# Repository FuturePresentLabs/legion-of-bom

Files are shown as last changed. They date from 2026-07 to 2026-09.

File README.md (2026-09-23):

<div align="center">

# legion-of-bom

### Prompt to PCB.

*One sentence in. A placed, routed, DRC-checked board out — and every value on it has a receipt.*









*SKiDLs are better with friends.*

</div>

```bash
lob spec stm32-codec --brief "stereo line in and out, no I2C setup" --out design
lob schematic design.json --out board.py
lob board board.py && lob drc out/board/board.kicad_pcb
```

That's a design brief becoming an STM32H743 audio board: a codec **decided**
from what you asked for, pins wired by the names in the official KiCad symbols,
every capacitor and strap **cited** to a page of a pinned datasheet, then placed,
routed and checked by KiCad's own DRC. No schematic drawn by hand, no pinout
typed from memory, no value you can't trace.

**legion-of-bom** turns circuit-as-code into manufacturing-ready outputs —
placed and routed boards, panels, Gerbers, a JLCPCB assembly package, build
guides and a priced BOM — in one pipeline instead of KiCad + spreadsheets +
manual ordering scattered across tools. It started with
[Puget Audio](https://pugetaudio.com) Eurorack modules and now designs
microcontroller boards too.

- 🎛️ **Ships real hardware.** The Puget Audio slew limiter builds from source to a
  DRC-clean, 0-unconnected fab package.
- 🧠 **Decides, doesn't hallucinate.** Every design choice is a bounded, typed
  decision — a choice, a probability, a rubric score — never free text. The
  rest is a pure function of those answers.
- 🧾 **Cites everything.** 0.5 mm pins escape through a router that measures
  clearance in exact geometry; decoupling values come with a verbatim datasheet
  quote a machine checks; anything it can't check waits for a human to sign.
- 📏 **Keeps score.** [PCBBench](https://github.com/FuturePresentLabs/pcbbench)
  runs brief → board → DRC against a rubric, so "does it work" has a number.

*(Badge numbers are generated — run `scripts/update-badges.sh` after tests,
families or datasheets change; don't hand-edit them.)* See
[`DESIGN.md`](./DESIGN.md) for the full design and [marbles](#issue-tracking)
for the live task graph.

## The pipeline

A circuit is defined as code (SKiDL), or decided from a design brief and then
rendered to code, and flows through composable stages:

```
brief ─(lob spec)─► spec ─(lob schematic)─► SKiDL circuit
                                              │
        lob run:  netlist → parse → ERC → simulate (ngspice) → verify → BOM
        lob board: place → legalize → route → .kicad_pcb → lob drc (kicad-cli)
        lob fab / guide / build: Gerbers + drill + CPL + BOM, assembly guide, Visual BOM
```

- **Typed decisions, curated families.** `lob spec <family> --brief "…"` asks a
  small number of bounded questions (a choice, a probability, a rubric score —
  never free text) of a System One–compatible endpoint through the shared
  [`ooda`](https://github.com/FuturePresentLabs/ooda) client, and writes a spec. `lob schematic` renders
  the circuit as a pure function of that spec. Families today: `fuzz-pedal`
  (plus `lob spec-chain` for chained gain stages) and `stm32-codec` (an
  STM32H743 with a PCM5102A + PCM1808, WM8731 or ES8388 codec).
- **Cited, not remembered.** A family's pinouts come from the official KiCad
  symbols, connected by pin name and checked against the symbol file (including
  pin-mux alternates). Every component value carries a verbatim quote from a
  page of a pinned datasheet — distributor copy, URL + SHA-256 — that is checked
  mechanically with `pdftotext`. Values read off a figure, or not stated in any
  pinned source, are recorded as readings; `lob schematic` lists every one no
  person has confirmed yet.
- **Layout for Eurorack and free boards.** A board with a panel is laid out
  against it (the PCB also derives its own minimum-width panel); a board without
  one gets a free rectangle sized to its parts. A negotiated-congestion router
  escapes 0.5 mm-pitch QFP/QFN pins and measures clearance in exact geometry.
- **Measured, not assumed.** Simulation checks textbook circuits against
  analytic values, `lob scope-probe` measures clipping as a SPICE claim, and
  [PCBBench](https://github.com/FuturePresentLabs/pcbbench) scores whole runs — brief to DRC — against a
  task rubric.

## Architecture

- **`legion-of-bom-core`** (`crates/core`) — the pipeline library: circuit model
  and the `CircuitSource` trait every stage reads through (DSL-agnostic, DESIGN.md
  2.3/3.3), placement, routing, rules, panels, fab, guides, SPICE, the curated
  families (`family.rs`) and datasheet citations (`datasheet.rs`).
- **`lob`** (`crates/cli`) — the command-line interface, a thin wrapper over the
  core library.
- **`legion-of-bom-web`** (`crates/web`) — the local read-only dashboard
  (`lob serve`) over the same core.
- **Parts library** — a global SQLite store (via SQLx) of part definitions keyed
  by MPN, with a `verified_by_human` gate on real board/BOM generation
  (`lob parts …`). Distributor clients (Mouser, JLCPCB) are sandboxed Lua scripts,
  not built-in Rust.

## Setup

Rust toolchain, plus the external tools the stages shell out to — each stage
fails with a clear error, never a panic, when its tool is missing:

- **KiCad 9** (`kicad-cli`, symbol + footprint libraries) — boards, DRC, fab
- **Python + SKiDL** in a `.venv` (or `$VIRTUAL_ENV`) — circuit scripts
- **ngspice** — simulation
- **poppler** (`pdftotext`) — datasheet citation checks

`lob doctor` reports what it found. API keys (`OODA_API_KEY` for `lob spec`,
`MOUSER_API_KEY`, `JLCPCB_*`) go in `~/.lob/credentials` or a repo `.env` — see
[`.env.example`](./.env.example).

## Quickstart

```bash
cargo run -p legion-of-bom-cli -- run examples/rc_lowpass.py        # simulate a textbook filter

lob spec stm32-codec --brief "stereo line in/out, no I2C setup" --out design
lob schematic design.json --out board.py                            # + unconfirmed readings
lob run board.py && lob board board.py && lob drc out/board/board.kicad_pcb
```

## Dev loop

Run the gates in this order — cheapest feedback first:

```bash
cargo check          # fast type/borrow check (run first, run often)
cargo test           # unit tests
cargo build          # produce the lob binary

cargo fmt --check    # formatting
cargo clippy --all-targets --all-features -- -D warnings   # lints, warnings are errors

# Checks that need the installed KiCad libraries and the pinned datasheets:
cargo test -p legion-of-bom-core -- --ignored
```

## Vendored assets

`assets/` carries real, sourced third-party panel-component footprints and
3D meshes (Eurorack-style jacks, pots, LEDs, switches) for hardware KiCad's
own stock libraries don't cover well. See [`assets/CREDITS.md`](assets/CREDITS.md)
for exact provenance, licenses (Unlicense, CC-BY 4.0 — both redistribution-
clean), and where to re-fetch them.

## Issue tracking

Work is tracked in **[marbles](https://github.com/FuturePresentLabs/marbles)**
(hosted, one writer per project), not markdown TODOs. Ids carried over unchanged
from beads. The roadmap (DESIGN.md §14) is modeled as epics:

```bash
marbles ready                 # what's available to work on now
marbles list --json           # everything, machine-readable
marbles show <id> --json      # details + dependencies
```

Closed means merged: finished work moves to `review` with its PR and closes on
merge.

## License

[AGPL-3.0-or-later](./LICENSE).

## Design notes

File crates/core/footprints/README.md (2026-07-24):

# Bundled sub-board footprints

Real KiCad footprints for Daisy sub-boards, embedded so a circuit can reference
them via the `LobModule:` library (see `crates/core/src/subboard.rs`).

`Daisy-Boards.pretty/` is vendored from Electrosmith's **DaisyKiCad** library
(https://github.com/electro-smith/DaisyKiCad), MIT-licensed — see
`DaisyKiCad-LICENSE`. Pad names are the physical Daisy pin names (`A1`…`D10` /
`A1`…`E10`), so nets map straight to the datasheet pinout.

| Footprint | Module | Mount |
|---|---|---|
| `DAISY_PATCH_SM` | Patch Submodule | through-hole 2×5 headers ×4 |
| `DAISY_PATCH_SM_SMT`  | Patch Submodule | SMT headers |
| `DAISY_SEED2_DFM` | Seed2 DFM | SMT (1.27 mm) female landing |
| `DAISY_SEED2_DFM_PTH` | Seed2 DFM | through-hole (1.27 mm) female landing |

The Daisy Seed itself is synthesized in `subboard.rs` (not vendored here).

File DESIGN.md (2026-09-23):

# Puget Audio Board Pipeline — DESIGN.md

Status: DRAFT — sections 1-3 filled in, 4-15 pending.

## Table of Contents

1. **Vision & Scope**
   1.1 Problem statement
   1.2 What "done" looks like
   1.3 Non-goals (v1)

2. **Architecture Overview**
   2.1 Pipeline stages (map to the 8-step loop)
   2.2 Orchestration model (CLI tool? library? workflow engine?)
   2.3 Canonical circuit representation (the IR that DSLs compile to / tools read from)
   2.4 Repo & project structure
   2.5 Multi-tenancy & auth
   2.6 Storage split: SQL stores vs. git-native

3. **Circuit Definition Layer**
   3.1 SKiDL (v1, Python)
   3.2 Path to a native Rust DSL (v2+)
   3.3 DSL-agnostic circuit IR — what it must capture to support multiple frontends
   3.4 Reusable component/subcircuit library (op-amp stages, OTA stages, RIAA networks, etc.)
   3.5 Global parts library (pinout/rating/SPICE-model verification — see also MCP.md)

4. **Validation Layer**
   4.1 ERC (first pass) — what it catches, what it doesn't
   4.2 Project-specific rule extensions (Eurorack power header conventions, panel mount checks)
   4.3 Parts verification gate (filled — see body)

5. **Simulation Layer**
   5.1 ngspice integration
   5.2 PedalKernel integration — reusing the existing accuracy/harness infrastructure
   5.3 What gets simulated pre-layout vs. what waits

6. **Layout & DFM**
   6.1 Format profiles (Eurorack, Guitar Pedal, Rack Mount, Desktop) — anchored connectors
   6.2 2-layer convention (ground pour default)
   6.3 Mode: Analog vs. Digital — cost-function weighting
   6.4 Critical-net tagging in SKiDL
   6.5 Iterative layout loop (place → route → check → repair)
   6.6 KiCad pcbnew integration (from IR/netlist to board file)
   6.7 DFM checks (JLCDFM + mechanical/3D collision checks)
   6.8 Manual layout escape hatch — where the human loop stays in
   6.9 PanelSpec trait — the format-agnostic seam (filled — see body)
   6.10 Silkscreen generation & validation (filled — see body)

7. **Panel Design**
   7.1 DXF output (filled — see body)
   7.2 SVG output (priority raised — see 7.7)
   7.3 KiCad-native panel workflow
   7.4 Mechanical fit checks against PCB (jack/pot alignment)
   7.5 Manual order tracking — no fab-vendor API available (filled — see body)
   7.6 Visual BOM / component sorting sheet (filled — see body)
   7.7 Drilling jigs + Lightburn SVG (filled — see body)
   7.8 Build-guide rendering (filled — see body)
   7.9 Parametric brand identity — curated, not generated (filled — see body)

8. **Manufacturing Outputs**
   8.1 Gerbers via KiCad (v1 path)
   8.2 Direct-to-gerber (future — if/when it's worth it)
   8.3 Output validation before submission

9. **BOM & PCBA Pipeline**
   9.1 BOM generation from IR
   9.2 CPL (component placement list) generation
   9.3 JLCPCB API integration (quoting, order creation, tracking)
   9.4 BOM accuracy/verification — this has to be airtight (filled — see body)
   9.5 Multi-vendor part sourcing rules (JLCPCB basic vs extended, LCSC fallback)
   9.6 Compatible-substitute suggestions (filled — see body)

10. **Thru-Hole BOM & Ordering**
    10.1 Distributor sourcing (LCSC/Mouser/DigiKey)
    10.2 Kitting for in-house assembly at FPL

11. **Part Stock & Inventory Management**
    11.1 Data model (parts, boards, revisions, quantities on hand)
    11.2 Shared-component tracking across SKUs (2OPFM, PHRSR/SCANNER/EG/TVCA, future Winterbloom line)
    11.3 Source of truth — where inventory state actually lives

12. **Reorder Automation**
    12.1 Trigger logic (thresholds, lead-time awareness)
    12.2 n8n integration
    12.3 Human-in-the-loop vs. fully automatic ordering

13. **QC, Test & Revision Control**
    13.1 Bench test / functional test procedure before ship
    13.2 Board revision scheme (silkscreen rev ↔ git tag ↔ IR version)
    13.3 Traceability (which rev shipped to which retailer/order)

14. **Roadmap & Milestones**
    14.1 Phase 0 — demo circuits (RC low-pass filter, then non-inverting op-amp gain
         stage) as end-to-end proof of concept, local-only. Goal: exercise every
         pipeline stage on textbook circuits with known-good answers before risking
         a real product design on an unproven pipeline
    14.2 Phase 1 — slew limiter (first real Puget Audio board), still local/localhost
    14.3 Phase 2 — MVP hardening covering must-have outputs (KiCad/PedalKernel/SPICE)
    14.4 Phase 3 — panel outputs (DXF/SVG/KiCad)
    14.5 Phase 4 — BOM/PCBA hardening + inventory (Dolt) + reorder automation
    14.6 Phase 5 — SaaS-ification: multi-tenancy, auth, hosted remote-repo connections
    14.7 Phase 6 — direct-to-gerber, additional DSLs (stretch)

15. **Open Questions**
    (running list — filled in as we go)

---

## 1. Vision & Scope

### 1.1 Problem statement
Small electronics hardware businesses (starting with Puget Audio) currently manage
circuit design, simulation, layout, BOM/PCBA ordering, and inventory across
disconnected tools — KiCad GUI, spreadsheets, manual retailer ordering. legion-of-bom
unifies this into one pipeline: circuit-as-code in, manufacturing-ready outputs and
live inventory/reorder state out.

### 1.2 What "done" looks like
Phase 0: an RC low-pass filter and a non-inverting op-amp gain stage, each defined in
SKiDL, flow through the full pipeline — validation, ngspice simulation checked against
textbook predicted values, KiCad layout scaffolding, BOM/CPL — entirely on one local
machine, no network-facing component. That proves the loop before any real Puget
Audio product design goes through it. Full "done" (later phases): a user defines a
circuit in SKiDL (or a future DSL) inside a git repo; legion-of-bom runs the same
pipeline, can quote and place a JLCPCB PCBA order via their API, tracks inventory in
Dolt, and triggers reorders — through a web dashboard, usable by more than one
tenant/business.

### 1.3 Non-goals (v1)
- Full autorouting/autoplacement — manual layout stays human-driven initially
- Replacing KiCad's schematic/layout editors outright — legion-of-bom orchestrates
  around them, doesn't replace them
- Multi-tenancy, hosted auth, remote repo connections, billing — v1 is local-only,
  single-user, no network-facing auth surface at all. SaaS-shaping is an
  architectural intent for later, not a v1 requirement

---

## 2. Architecture Overview

### 2.1 Pipeline stages
Maps to the 8-step loop (Sections 4–13 below), plus panel design and QC/revision
control as first-class stages rather than afterthoughts.

### 2.2 Orchestration model
A Rust core library (`legion-of-bom-core`) exposes each pipeline stage as a composable
function/trait. A CLI (`lob`) wraps the library for local, scriptable use. A web
backend (axum — same stack as Understory) wraps the *same* library for the hosted
dashboard, so nothing is web-only — anything the dashboard can do, the CLI can do
headless.

### 2.3 Canonical circuit representation
Deferred per decision: SKiDL-native for now, IR extracted once a second DSL is real.
Flag for later sections: pipeline stages downstream of circuit definition
(validation, sim, layout) should still be written against a thin internal interface
now, even before extraction, so the eventual IR refactor doesn't ripple through
everything that consumes circuit data.

### 2.4 Repo & project structure
- **FuturePresentLabs/legion-of-bom** — the tool itself (core lib + CLI + web
  backend), AGPLv3
- **Board/circuit repos** — one per project (e.g. `puget-audio-2opfm`,
  `puget-audio-slew-limiter`), each can hold multiple related circuits, plain git.
  In v1, these are local clones on the machine running `lob` — the CLI/backend
  shells out to `git` directly, no remote-hosting integration yet. The
  Forestry.io-for-KiCad model (connecting to *someone else's* remote repo) is a v2+
  concern once SaaS-ification happens
- **Inventory data** — lives in Dolt, not in the circuit git repos (see 2.6)

### 2.5 Multi-tenancy & auth (deferred to a later phase)
v1 is local-first and single-user: the CLI runs git commands directly against
locally-cloned repos, and the web dashboard runs on localhost with no auth layer at
all. Multi-tenancy, hosted repo connections, and auth (WebAuthn passkeys vs GitHub
OAuth vs something else) only get designed once the core pipeline loop — schematic
through inventory — actually works end-to-end for one user. Not designing this now
on purpose; revisit in Section 14 roadmap.

### 2.6 Storage split: SQL stores vs. git-native
Circuit definitions (SKiDL files, KiCad projects) stay in plain git — they're
file-based already and git's native diff/PR tooling works well on them. Structured,
cross-project data (parts, panel orders, and eventually stock levels/reorder
thresholds) lives in a SQL store instead, for the query/aggregation layer plain
files can't do well.

Which SQL store is deliberately not one answer for every table. The **parts
library** (Section 6.8, `crates/core/src/parts.rs`) is a single local SQLite file
via `sqlx` — no per-write history, a write just overwrites what was there; nothing
in its verification-gate workflow needed git-like branching/diffing, so paying
for it was pure overhead. **Panel orders** (Section 7.5, `crates/core/src/panel.rs`)
are still Dolt-backed, unmigrated — that store keeps the git-like versioning this
section originally described for all of inventory, until it's revisited on its
own.

---

## 3. Circuit Definition Layer

### 3.1 SKiDL (v1, Python)
SKiDL is the circuit-definition frontend for Phase 0 and Phase 1. Each circuit is a
Python script using SKiDL's `Part`/`Net`/`Pin` API; running the script produces a
netlist (`generate_netlist()`) that `legion-of-bom-core` shells out to KiCad's
`pcbnew` Python API to turn into a board file. SKiDL also runs `ERC()` for first-pass
validation before anything reaches netlist generation (Section 4).

### 3.2 Path to a native Rust DSL (v2+)
Explicitly deferred. Not designed now, not blocking Phase 0/1. When it happens, it
targets whatever canonical IR gets extracted in 3.3 — same target SKiDL will be
retrofitted onto, not a parallel one-off format.

### 3.3 DSL-agnostic circuit IR
Deferred per the Section 2.3 decision: SKiDL-native now, IR extracted once a second
DSL is real. Practical consequence for Phase 0 build: `legion-of-bom-core`'s
validation/simulation/layout stages should consume circuit data through a small
internal trait (e.g. something like a `CircuitSource` trait returning parts/nets)
rather than calling SKiDL-specific types directly everywhere — even though the only
implementation right now is "read a SKiDL-generated netlist." This keeps the eventual
IR extraction to one new implementation of that trait instead of a rewrite.

### 3.4 Reusable component/subcircuit library
No longer empty in practice — the LM13700 bias-generator work (control
voltage → IABC) turned out to be genuinely shared between the slew limiter
and crossfader, the first real evidence of reuse the deferred trigger
condition was waiting for. Extracted into `circuits/lib`, git-native per the
Section 2.6 storage split (circuit content, not structured cross-project
data).

**Each subcircuit entry declares what it needs from the part filling its
role, not just which part was used** — this is what makes substitution
(Section 9.6) possible without a hand-maintained pairwise compatibility
table:

```json
{ "subcircuit": "unity_gain_buffer", "requires": {"min_gbw_mhz": 1, "max_vos_mv": 10} }
{ "subcircuit": "crossfader_signal_path", "requires": {"min_gbw_mhz": 3, "max_vos_mv": 3, "max_noise_nv_hz": 15} }
{ "subcircuit": "ota_bias_generator", "requires": {"part_family": "LM13700-compatible dual OTA"} }
```

A part that's a valid substitute for one role (e.g. TL072 in a buffer) isn't
automatically valid for another (e.g. the crossfader's signal path, which
needs tighter GBW/noise) — the requirement lives with the *role*, not as a
property hung off a specific part pairing.

### 3.4.1 What's shared vs. not — the LM13700 case, concretely
Only the **bias generator** (CV-to-IABC resistor network) is genuinely
reusable between the slew limiter and crossfader — same math, same purpose.
The OTA *application* around it differs and stays circuit-specific: the slew
limiter runs its OTA as a bounded current source (no diode linearization
needed), the crossfader runs its OTA pair as a linear signal path (diode
linearization required, per the derivation in `crossfader-circuit.md`).
Modeling the whole LM13700 circuit as "one subcircuit, reused twice" would
have been wrong — the boundary is narrower than the IC, and getting that
boundary right mattered more than reusing as much code as possible.

### 3.5 Global parts library (pinout/rating/SPICE-model verification)
**Status: in progress — tracked as epic `okm`, 5 P1 tasks open (schema,
distributor sourcing, `fetch_datasheet`, the `verified_by_human` gate,
MPN-based `define_circuit`).** Unblocked by Phase 0's close; the first proven
slice already exists — Phase 0 demonstrated components carrying their own
SPICE models with a resolver seam this library plugs into, ahead of the full
schema being built.

`define_circuit` — whether invoked directly (writing SKiDL by hand), via the
`lob` CLI, or via an MCP-driving agent (see MCP.md) — resolves parts by MPN
against a **global, SQLite-backed parts library**, not model/training memory and
not a per-project file. This is core `legion-of-bom-core` architecture, not an
agent-only construct: the same trust rules apply regardless of entry point.

- **Sourcing order**: distributor-official CAD library (DigiKey's in-house
  KiCad library, JLCPCB/EasyEDA) → broader CAD library (SnapEDA/Ultra
  Librarian, checking verification status) → PDF datasheet extraction as
  fallback, sourced only from a distributor API's datasheet URL field, never a
  general web search. See LIBRARIES.md for the full curated source list.
- **Every extracted pin/rating carries a citation** (source, page/section) —
  see MCP.md Section 1 for the full schema (`parts`, `part_pins`,
  `part_ratings` tables)
- **SPICE models are a distinct artifact from pinout/ratings, sourced
  differently and verified differently.** They typically come from the
  manufacturer directly (e.g. TI's own product page), not a distributor API
  field, and multi-channel packages often need a wrapper subcircuit (the raw
  manufacturer model is single-channel; a dual op-amp needs it instantiated
  twice with matching pin order). Verification here isn't "read the pin
  number correctly" — it's "run a known textbook case and confirm the
  simulated result matches," the same evidentiary bar Phase 0 held its own
  demo circuits to. See MCP.md and the `part_spice_models` table concept for
  schema detail.
- **`verified_by_human` gates real use**: a part can be fetched and extracted
  automatically, but `layout` and `generate_bom` (Section 6, Section 9) refuse
  to run against any part that hasn't been human-confirmed at least once.
  Verification is global and one-time per part — reused across every future
  project, not re-checked per repo
- This exists specifically to prevent a repeat of the LM13700-pinout-from-
  memory mistake made earlier in this project — the fix is structural
  (a gate the pipeline enforces) rather than a process reminder to double-check

**Parts library ≠ BOM — related, not the same epic.** The parts library
answers "is this part definition trustworthy" (pinout, ratings, SPICE model,
keyed by MPN) — no pricing, no quantities, no vendor stock, that's not its
job. BOM generation (Section 9.1) *reads* this library to know which MPNs are
real and verified, then adds something the parts library was never meant to
hold: live pricing/stock from a distributor API (Mouser, to start). Sequencing
consequence: the parts-library epic unblocks BOM, but BOM is a separate
epic layered on top, not a subtask inside this one.

Full detail, tool schemas, and the agent-facing flow live in MCP.md — that
document describes the agent surface of this same core mechanism, not a
separate implementation of it.

---

## 6. Layout & DFM

*(Sections 4–5 remain TOC-only placeholders — filled out of order because this was
the harder architectural problem to work through)*

### 6.1 Format profiles (Eurorack, Guitar Pedal, Rack Mount, Desktop) — anchored connectors
v1 scope is deliberately limited to four form factors rather than general PCB
layout. Each format gets a `PanelProfile`: mounting hole pattern, panel
dimension convention (Eurorack HP, pedal enclosure size classes, rack U-height,
desktop footprint), and a library of standard connectors with fixed footprints
and 3D models. Critically, connectors defined by a format's `PanelProfile`
(jacks, pots, switches) are **placement-anchored** — their position is
determined by the panel spec, not by the layout optimizer. This shrinks the
free-placement problem to just the support components (passives, ICs) instead of
the whole board, which is what makes an iterative loop tractable instead of a
general NP-hard placement search.

**Board side is a real, current requirement for Eurorack, not a deferred
one.** The existing Super Synthesis resurrection line (PHRSR/SCANNER/EG/TVCA)
is genuinely double-sided in production: SMD/PCBA components on one side,
THT + silkscreen on the opposite side — with the power header as the sole
exception (THT, but placed on the PCBA side rather than the THT side). This
means every footprint in the anchored-cutout and free-placement data model
needs a `side: front | back` attribute, and the format-specific 3D-model
library (6.7) needs both-side clearance data, not just one. **Guitar Pedal
stays single-sided** (matches real THT pedal convention, no change there) —
this is an Eurorack-specific requirement, not a general one, and shouldn't
be generalized into "all formats need both-side support" without evidence.

### 6.2 2-layer convention (ground pour default)
Hard v1 constraint: 2 layers only, matching real fabrication experience and no
near-term need for more. Default convention: bottom layer is a solid ground
pour, top layer carries signal and power traces, with via stitching down to
ground where needed. **This needs reconciling with 6.1's double-sided
requirement for Eurorack** — a solid ground pour on the back copper layer and
components mounted on that same physical side aren't mutually exclusive (SMD
parts can sit on a layer that's mostly ground-poured, routed around), but it
means the "bottom = pure ground, no components" mental model implicitly
carried through this section's earlier drafts was wrong for Eurorack
specifically, even though it stayed true for the THT-pedal single-sided case.
Worth a closer pass once double-sided placement logic is actually being
built, not just flagged here. This substantially replaces manual star-ground
topology work for most nets — a solid pour gives a low-impedance return path
largely "for free," rather than requiring every ground connection to be
individually routed to converge at one point. Reduces one of the most
error-prone parts of analog layout (see the phono-preamp grounding
discussion) to a default that mostly just
works, with critical-net tagging (6.4) as the escape hatch for the nets where it
doesn't.

### 6.3 Mode: Analog vs. Digital — cost-function weighting
Project-level mode selection (not auto-detected) picks which violation-scoring
weights the iterative loop (6.5) uses:
- **Analog mode:** weights ground-pour integrity, critical-net proximity
  (feedback networks, decoupling caps within a short distance of IC power pins),
  and channel symmetry (stereo matching)
- **Digital mode:** weights trace length, via count, and (later) controlled
  impedance / differential pair matching
- **Mixed:** both weight sets active, with per-net critical tagging (6.4) doing
  the heavy lifting to tell the loop which rules apply where

### 6.4 Critical-net tagging in SKiDL
Manual, not auto-detected (confirmed decision). The circuit author explicitly
tags nets that need analog-careful treatment at definition time — e.g. a
feedback network net, a high-impedance input stage net, a matched-pair net for
stereo channels. Auto-detection from topology was considered and rejected:
whether a net is "critical" often depends on domain judgment (audio-rate,
high-impedance, sensitive to parasitic coupling) that isn't cleanly inferable
from graph structure alone. Practical shape: something like a `critical()`
wrapper or tag argument on the net when defined in SKiDL, carried through into
the netlist/IR so the layout loop can read it without re-deriving it.

### 6.5 Iterative layout loop (place → route → check → repair)
Not general autorouting — guided iterative repair over the *free* (non-anchored)
components and nets only:
1. Auto-place free components, seeded near their anchored neighbors (e.g. a
   decoupling cap seeded close to the IC it decouples)
2. Auto-route non-critical nets against the current mode's cost weights
3. Check violations: electrical DRC, mechanical/3D collision checks (6.7),
   critical-net rules (e.g. "is this tagged critical net physically short and
   direct, or did the router send it around the board")
4. If violations exist, generate a targeted repair (not a full re-place) and
   recheck
5. Exit condition is **not** "zero violations" — critical nets that the loop
   can't confidently resolve get surfaced explicitly for manual routing, not
   silently left broken or silently "solved" by a heuristic that shouldn't be
   trusted on that net

Each attempt is a natural git commit (circuit repos are already git-native),
which gives the loop's history for free — diffable, revertable, no separate
state-tracking needed.

### 6.6 KiCad pcbnew integration (from IR/netlist to board file)
**Decision: `kicad-ipc-rs`, talking to KiCad's IPC API — not the SWIG-based
Python `pcbnew` bindings.** SWIG is technically usable on the current stable
release (KiCad 10) but is deprecated as of KiCad 9, in maintenance mode only,
and scheduled for full removal in KiCad 11 — building `legion-of-bom-core`
against it means a forced rewrite the moment KiCad is upgraded. The IPC API is
KiCad's actively-developed, forward-looking programmatic interface and is
where `kicad-python` (the official Python equivalent) already lives.

**v1 connection mode: attach to a running KiCad GUI instance**, not a headless
server. The IPC API in KiCad 9/10 only supports talking to an already-running
KiCad session — there is no headless option yet on the current stable release.
Rather than standing up Docker/xvfb to fake a headless environment (real
overhead, especially unpleasant on macOS), v1 simply requires KiCad open
locally and connects `kicad-ipc-rs` to it — a reasonable requirement given
`legion-of-bom` is already local-first and single-user (Section 2.5), and this
matches the actual working setup rather than solving a CI/server problem that
doesn't exist yet.

**Known upgrade path, not a maybe**: `kicad-cli api-server` (headless IPC
server, no GUI) ships as of KiCad 11, and `kicad-python` already has a
`headless=True` connection mode built specifically around it — same IPC
protocol, just a different socket to connect to. When `legion-of-bom` needs
true headless (CI, the eventual SaaS phase in 14.6), the change is which
socket `kicad-ipc-rs` connects to, not a rewrite of how it talks to KiCad.
Document this here so it isn't re-litigated later: **v1 requires KiCad running
locally, on purpose, with a known and already-supported path off of that
requirement when it's actually needed.**

**Mechanics**: netlist (from SKiDL, Section 3) → `kicad-ipc-rs` client calls
into the running KiCad instance to create/update the board, place footprints
(anchored per Section 6.1, free-placed per the iterative loop in 6.5), and
drive routing attempts → violations read back via the same IPC connection
(Section 6.5 step 3) → once clean, Gerbers exported via `kicad-cli pcb export
gerbers` (a separate, already-headless CLI command, not gated by the
GUI-instance requirement above).

### 6.7 DFM checks (JLCDFM + mechanical/3D collision checks)
Two kinds of check: standard electrical/manufacturing DFM (JLCDFM or
equivalent — trace/space rules, hole sizes, etc.) and mechanical collision
checks enabled by having 3D models of every component — catching a jack body
colliding with a neighboring part, or a panel cutout misaligned with its PCB
footprint, before it becomes a physical mistake instead of just an electrical
one.

### 6.8 Manual layout escape hatch — where the human loop stays in
Any net the iterative loop can't resolve with confidence (per its exit
condition in 6.5) gets flagged for manual routing rather than forced through a
heuristic. Given the RIAA/phono-style circuits discussed earlier are exactly
the case where layout mistakes are audible and hard to diagnose after the fact,
this escape hatch is treated as a feature, not a shortfall — the loop's job is
to auto-resolve what's mechanically resolvable and clearly surface what needs
judgment.

### 6.9 PanelSpec trait — the format-agnostic seam
Same move as Section 3.3's deferred circuit IR, applied to panels: rather than
designing shared geometry across all four formats now (Eurorack, Guitar
Pedal, Rack Mount, 500-series) — or the reverse mistake of hard-coding
Eurorack-specific concepts (HP, U) directly into layout code — a thin
`PanelSpec` trait is defined now, implemented fully for Eurorack only (what's
actually shipping), with the other formats' implementations deferred until
one of them is actually being built.

**Shape of the trait**: dimensions in mm (each format's native units —
HP/U for Eurorack, enclosure size class for pedals, rack U-height ×
19"-fraction, 500-series' fixed slot — translate into mm through the
implementation, not exposed as universal concepts to the rest of the
pipeline), a mounting-hole list, and a list of anchored cutouts (position,
rotation, footprint reference) that Section 7's DXF export and Section 6's
layout loop both read through the trait rather than assuming Eurorack.

**Why this isn't "design all four now" or "hard-code Eurorack now"**: the
four formats aren't similar enough to unify speculatively. 500-series in
particular is mechanically the odd one out — audio I/O typically runs through
a card-edge connector into the shared lunchbox bus, not individual
front-panel jacks the way Eurorack/pedal/rack all work — forcing it into the
same anchored-jack-pot cutout model used for the other three would be wrong,
not just incomplete, so its `PanelSpec` implementation waits until it's
actually being built rather than being guessed at now.

### 6.10 Silkscreen generation & validation
Not previously covered — the sexp-generation and DRC-readback work (6.6)
solved copper/routing/electrical-rule checking, but silkscreen (reference
designators, polarity marks, pin-1 indicators) is a distinct KiCad layer
untouched by any of that.

**v0 scope**: accept KiCad's default reference-designator auto-placement
rather than building custom placement logic — real auto-arrangement of
silkscreen text to avoid overlaps is its own hard layout-adjacent problem
(similar in spirit to general label-placement optimization), and not worth
solving before a single real board has shipped. What *is* worth adding: a
`silkscreen_collision` violation type in the DRC-readback check step (6.5),
since silkscreen-over-pad or silkscreen-over-silkscreen isn't an electrical
DRC violation and would otherwise pass the existing check silently.

**Why this matters more given the THT pedal direction specifically**:
reference designators and polarity marks are directly useful to someone
hand-assembling a board from a BOM — not cosmetic. Polarity marks in
particular need to be correct and visible, since wrong-polarity assembly
(diodes, electrolytic caps, ICs) is a common real failure mode in DIY-style
builds. This ties directly into 7.8's build-guide rendering — the "populated
board" reference render needs accurate silkscreen to be useful as a guide,
not just accurate copper.

**Low risk from board density for the near-term targets**: THT's low part
count and 0.1" grid spacing (per the THT-vs-SMD discussion) makes silkscreen
collisions rare in practice — another reason THT is a forgiving first real
target, this time for a layer nothing has touched yet rather than for
routing.

---

## 4. Validation Layer

*(4.1 ERC and 4.2 project-specific rule extensions remain TOC-only — filling
in 4.3 out of order because it's a cross-cutting concern that also touches
Sections 3 and 9)*

### 4.3 Parts verification gate
Before `layout` (Section 6) or `generate_bom` (Section 9) run, validation
checks that every part referenced in the circuit has `verified_by_human =
TRUE` in the global parts library (Section 3.5) and that the circuit's
open-questions checklist has no unresolved items. This is enforced inside
`legion-of-bom-core` itself — identical behavior whether the pipeline is
driven by the `lob` CLI directly or by an agent through MCP (see MCP.md
Section 1.4 and 2.2). Failing either check blocks the run and surfaces the
specific unresolved items rather than proceeding on unverified data — the
structural fix for the LM13700-pinout-from-memory mistake made earlier in
this project.

---

## 7. Panel Design

*(7.2–7.4 remain TOC-only — filling in 7.1 and 7.5 now since they're the
concrete near-term ask: get a real DXF out, and know whether it's been
ordered, given no fab vendor offers API automation yet)*

### 7.1 DXF output
Panel outline and cutouts (jack holes, pot holes, mounting holes, any
silkscreen-equivalent engraving) are exported to DXF from the same
`kicad-ipc-rs` connection used for the board itself (Section 6.6) — the panel
is its own KiCad PCB-editor-adjacent artifact (either a dedicated mechanical
layer/outline within the project, or a separate panel-only board file
depending on how the `PanelProfile`, Section 6.1, is implemented), with
geometry driven by the per-module physical layout (jack/pot/LED positions,
HP width) that DESIGN.md flagged as a real, currently-undesigned input.
`kicad-cli`'s existing plot/export tooling handles the actual DXF write —
same already-headless CLI path used for Gerber export in 6.6, not gated by
the "KiCad GUI must be running" requirement that applies to interactive
IPC operations.

DXF is the priority format because it's what both SendCutSend and OSH Cut
actually want as upload input (confirmed via their own tutorials/workflows) —
SVG (7.2) is lower priority until there's a concrete reason to need it.

### 7.5 Manual order tracking — no fab-vendor API available
Neither SendCutSend nor OSH Cut expose a public order-submission API (confirmed
— both are upload-a-file-to-a-web-app workflows only), unlike JLCPCB/Mouser/
DigiKey. So panel ordering itself stays a manual step: `legion-of-bom`
generates the correct DXF, a human uploads it and places the order on the
vendor's site. What *is* automatable is tracking status of that manual step,
so it doesn't get lost the way an untracked step easily does.

**Storage: a `panel_orders` table in its own Dolt-backed store (Section 2.6,
Section 11)** — structured, queryable, cross-project data, the same category
as parts verification and inventory, not project-specific circuit content
that belongs in git. (Not the same store as the parts library, which moved to
plain SQLite — see 2.6.)

```sql
CREATE TABLE panel_orders (
  id INT PRIMARY KEY,
  module VARCHAR(64) NOT NULL,       -- e.g. "crossfader-v1"
  dxf_path TEXT NOT NULL,            -- path/commit ref to the generated DXF
  vendor VARCHAR(32),                -- "sendcutsend" | "oshcut" | other
  status VARCHAR(16) DEFAULT 'not_ordered',  -- not_ordered | ordered | shipped | received
  ordered_at DATETIME,
  tracking_ref TEXT,                 -- vendor order/tracking number, entered manually
  notes TEXT
);
```

`lob panel status <module>` reads current state; `lob panel mark-ordered
<module> --vendor oshcut --tracking <ref>` updates it — simple manual CLI
commands standing in for what an API webhook would otherwise do automatically.
**Explicitly deferred, not designed away**: if either vendor adds a real API
later, or if this becomes a big enough part of operations to justify it, the
manual `mark-ordered` step gets replaced by an actual API call updating the
same table — the schema doesn't need to change, just how `status` gets set.

### 7.6 Visual BOM / component sorting sheet
Same underlying data as Section 9.1's BOM — grouped and rendered for a human
sorting physical parts by hand, not for procurement. No new data dependency:
this is a rendering template layered on the existing BOM output, cheapest
item in this set of additions. General enough to apply to any format, not
Guitar-Pedal-specific.

### 7.7 Drilling jigs + Lightburn SVG
Two related outputs, both consuming data `PanelSpec` (Section 6.9) already
produces:

- **3D-printable drilling jigs** — STL generated from the anchored-cutout
  hole positions already computed for DXF export (7.1), targeted at a small,
  fixed library of standard enclosure sizes (1590B, 1590BB, 125B, etc.) —
  exactly the kind of format-specific standardization Guitar Pedal has and
  Eurorack (bespoke per-module panels) mostly doesn't, which is why this
  lands here rather than as a general Section 7 feature.
- **Laser SVG for Lightburn** — this is Section 7.2 (SVG output), previously
  deprioritized for lack of a concrete use case. Pedal enclosure engraving
  and laser-cut drilling templates are that use case — priority raised for
  the Guitar Pedal line specifically, not a general re-prioritization of 7.2.

Both are alternate exports of geometry the pipeline already computes for DXF
— real work, but not a new data problem.

### 7.8 Build-guide rendering
The one genuinely new subsystem in this set, not a reformat of existing data.
Needs two things that don't exist elsewhere in the pipeline yet:

- **Rendered board views** — a populated-board 3D render (KiCad's rendering
  capability, same general approach `protorack-kicad`/`pcb2blender` use per
  LIBRARIES.md) with a highlight box overlaid at the current step's footprint
  position. Deliberately not real photography — avoids needing physical units
  reshot per board revision, which real photos would require.
- **Build sequencing** — a step order (typically low-profile-first: resistors
  → diodes → sockets → caps → tall/tall-bodied parts last) that has to be
  derived or specified per circuit; nothing in the pipeline currently produces
  this. Real new scope, sized as its own small epic rather than a BOM-export
  add-on.

Scope note for all of 7.6–7.8: layered on top of the Guitar Pedal `PanelSpec`
implementation, not before it exists — same gating already applied to
500-series and the rest of the layout epic.

### 7.9 Parametric brand identity — curated, not generated
The goal: boards and panels should read as designed products, not raw
pipeline output — including the ones that came out of the pipeline entirely
automatically. Same automatable/manual split already used for 7.8's labels,
applied to brand identity as a whole:

- **Automatable, parametric layer**: a small, fixed set of house-style rules
  — consistent silkscreen typography, a logo placement rule expressed as a
  function of panel dimensions (e.g. "bottom-center, scaled to N% of panel
  width, M mm from the bottom edge") rather than a fixed pixel position, a
  consistent border/frame treatment, a defined finish/color palette per
  product line. Applied programmatically to every board via the same
  `PanelSpec`/silkscreen (6.10) generation path — not hand-laid-out per
  board, but not generic defaults either.
- **Stays manual/curated**: actual illustration, one-off artwork, anything
  that's a genuine creative choice rather than a systematic rule. Same
  reasoning as everywhere else in this doc that draws this line (6.8's
  layout escape hatch, 7.8's labels) — automate what's mechanically
  derivable from a rule, surface what needs a human's eye.

**The actual risk this section exists to name**: a parametric system that
*invents* its own placement/spacing heuristics on the fly will read as
generated, no matter how technically correct it is — the "curated, not
generated" feel comes from the rules themselves being designed once, by a
human, and applied consistently, not from the automation being clever. This
matches the pipeline's consistent posture elsewhere (verification gates,
`research_topology`'s citation requirement, critical-net tagging) — the tool
executes and applies judgment that's been made deliberately, it doesn't
originate it.

**Practical shape**: a small "brand kit" — logo as a scalable vector (not a
fixed-resolution raster, so it holds up across HP widths and pedal enclosure
sizes), a typography choice for legends, and the placement-rule set above —
stored once as a shared asset referenced by every `PanelSpec` implementation
(Eurorack, Guitar Pedal, and beyond), not duplicated per product line. Given
it's genuinely cross-project brand identity rather than per-circuit content,
this likely belongs alongside the other shared/global concerns (parts
library, panel-order tracking) rather than living inside any one circuit
repo — exact storage mechanism (Dolt vs. a dedicated `brand/` directory in
the `legion-of-bom` repo itself) is an open implementation detail, not
resolved here.

---

## 9. BOM & PCBA Pipeline

*(9.1–9.3 and 9.5 remain TOC-only — filling in 9.4 out of order for the same
reason as 4.3 above. Note: 9.1 depends on the parts library (Section 3.5,
epic `okm`) but is its own separate epic — BOM adds live distributor pricing
on top of the parts library's verified-MPN data, it doesn't live inside the
parts-library epic. Mouser-priced BOM CSV is the current priority for 9.1.)*

### 9.4 BOM accuracy/verification — this has to be airtight
BOM generation reads part records (pricing, stock, footprint) from the same
global parts library used by circuit definition and layout (Section 3.5), not
a separate lookup. Practical consequence: a part's `verified_by_human` status
is not just a layout-time gate — `generate_bom` checks it too, for the same
reason. An unverified pinout is a layout risk; an unverified part record feeding
a real JLCPCB/Mouser/DigiKey order is a money risk on top of that, since a
misidentified part (wrong package, wrong footprint, wrong voltage rating) can
turn into a bad PCBA order rather than just a bad board file. Same gate,
enforced at the same core layer, for both reasons at once.

### 9.6 Compatible-substitute suggestions
**Advisory only — never automatic.** A pin-compatible part is not
automatically an acceptable substitute for a specific circuit; it's a
candidate that still has to clear the requirements of the *role* it would
fill (Section 3.4's subcircuit `requires` blocks). Two-part mechanism:

- **`pin_compatible_groups`** — a small, hand-maintained table of physically
  drop-in part families (op-amp pinout-compatible groups, etc.), each with
  its own `verified_by_human` flag. This is the only genuinely stable fact
  worth caching, since footprint/pinout compatibility doesn't change.
  ```sql
  CREATE TABLE pin_compatible_groups (
    group_id INT,
    mpn VARCHAR(64),
    package VARCHAR(32),
    verified_by_human BOOLEAN DEFAULT FALSE
  );
  ```
- **Live requirement check, not a stored relation** — at `generate_bom` time,
  if a primary MPN has low/zero stock, pull every part sharing its
  `pin_compatible_groups` entry and check each against the *subcircuit's*
  declared requirements (using the already-stored `part_ratings` from
  Section 3.5) — not a hardcoded "part X substitutes for part Y" fact, which
  would silently ignore that the same substitution can be fine in one role
  (a buffer) and wrong in another (a noise-sensitive signal path). Passing
  candidates are surfaced to the human for approval at BOM time; nothing
  swaps automatically.

**Explicitly out of scope for now**: automatic board re-layout in response to
a substitute with a different footprint ("intelligent respin"). Depends on
the iterative layout loop (Section 6.5) being mature enough to safely
re-run place/route/DRC unattended, which it isn't yet — revisit once layout
itself is solid, not before.

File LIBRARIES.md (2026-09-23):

# legion-of-bom — Library Sources (LIBRARIES.md)

Status: DRAFT. Reference doc, not architecture — a curated registry of where
symbol/footprint/3D-model/SPICE data comes from, what's known about licensing,
and what tooling already exists to import from each source.

**Scope note**: license fields here are informational metadata surfaced to the
user, not a pipeline gate. `legion-of-bom` doesn't police how end users use a
library in their own designs — that's between them and the library source.
The one place this project has actual exposure is if `legion-of-bom` itself
bundles/redistributes library files as part of its own repo (see the
CC-BY-SA "collection" clause below) — that's a narrower, separate concern from
general usage tracking.

---

## 1. Distributor-official (highest trust, matches existing sourcing rules)

| Source | What it provides | License notes |
|---|---|---|
| **KiCad official libraries** (`kicad-symbols`, `kicad-footprints`) | Symbols, footprints, some 3D models. Includes community-contributed Eurorack parts already merged in (QingPu 3.5mm jacks, Alpha pots) | **Confirmed**: CC-BY-SA 4.0. Using the library in your own design does NOT require your design to be CC-BY-SA — only *redistributing the library itself as a collection* (including modified) requires same-license + attribution retained. Cleanest, best-documented license of anything on this list. |
| **DigiKey official KiCad library** | In-house, applications-engineering-built | License not confirmed in research — check directly before relying on specifics |
| **JLCPCB/EasyEDA library** (via `JLC2KICAD_lib` conversion) | Symbols/footprints/3D models tied to the JLCPCB Parts API already integrated | License not confirmed — check LCSC/EasyEDA terms directly |

## 2. Broad third-party providers (large catalogs, mixed trust)

| Source | What it provides | License notes |
|---|---|---|
| **SnapEDA** (now "SnapMagic Search") | Millions of parts, automated + manual verification, verification badge system | Free to use in your own designs per general commercial understanding — actual ToS for redistribution not confirmed here, check directly |
| **Ultra Librarian** | Similarly large catalog, many CAD tool integrations | Same caveat as SnapEDA |
| **SamacSys** (component search engine, now largely folded into Ultra Librarian's ecosystem) | Same category | Same caveat |

## 3. Eurorack-specific community libraries

| Source | What it provides | License notes |
|---|---|---|
| **`danroblewis/kicad-eurorack-tools`** | Not just parts — includes a pcbnew plugin that draws eurorack-spec'd panel cutouts pre-aligned for Alpha pots, Thonkiconn jacks, and LED holes. Directly relevant to Section 7 (Panel Design) | License not confirmed — check repo |
| **`30350n/protorack-kicad`** | Careful, manufacturer-spec or friction-fit footprints, every part has a matching high-quality 3D model. Pairs with `pcb2blender` for renders | License not confirmed — check repo |
| **`nathanaelnoir/KiCad-Eurorack-Library`** | Personal working library, validated against KiCad 9 | Has its own LICENSE.md — but explicitly flags that some 3D/STEP files weren't created by the repo owner and may need separate attribution/permission. **License is not uniform within this one repo** — check per-asset, not just per-repo |
| **`russellmcc/eurorack_kicad`** | Panel/footprint templates, referenced in community forum threads as a known-good starting point | License not confirmed |
| **`nebs/eurocad`** (and `wgd-modular/eurocad` fork) | Components/footprints used in the author's own Eurorack modules | License not confirmed |
| **`jjradler/eurorack-kicad-library`** | Hard-to-find parts for Eurorack development | License not confirmed |
| **`benjiaomodular` org** (`KiCadLibraries` repo + related) | Part of a broader ecosystem of actually-shipped open Eurorack module designs (includes a MiniVCA built around LM13700 — same part as the slew limiter) | License not confirmed — but the sibling shipped-module repos may be worth studying as reference designs too, separate from the library question |
| **`tristan-smith/HA_KicadLibraries`** | Common audio electronics/Eurorack footprints (jacks, pots, switches) | License not confirmed |
| **AudioMorphology's KiCad front panels repo** | Panel templates specifically (not a footprint library) | License not confirmed |

---

## 4. Import & library management tooling (don't reinvent these)

- **KiCad's built-in Plugin and Content Manager (PCM)** — several of the
  libraries above (e.g. `kicad-eurorack-tools`) ship a `repository.json`
  specifically so they install directly through PCM rather than manual file
  copying. Check for a PCM manifest before writing custom import code for any
  given source.
- **"Import-LIB-KiCad-Plugin"** — existing KiCad plugin that automates pulling
  downloads from SnapEDA, SamacSys, and Ultra Librarian into KiCad's library
  format, rather than manual per-part download-and-place.
- **`JLC2KICAD_lib`** — existing Python tool converting JLCPCB/EasyEDA library
  entries (schematic, footprint, 3D model) into native KiCad format. Natural
  fit given JLCPCB is already integrated for BOM/PCBA.
- **SamacSys Library Loader** — desktop tool for searching/pulling parts
  directly into a CAD tool's library path.
- **`KICAD_3RD_PARTY` environment variable convention** — community pattern
  for keeping t[118;1:3uhird-party library sources in clearly separated, trackable
  folders (e.g. one subfolder per source) rather than merging everything into
  one undifferentiated pile — useful convention for `legion-of-bom` to adopt
  when managing multiple sources with different trust/license status.

**Practical implication for `search_part`/`fetch_datasheet`**: prefer driving
these existing tools (PCM installs, `JLC2KICAD_lib`, the Import-LIB plugin)
over writing new scrapers/parsers against each source's website — several of
these sources already have purpose-built, community-maintained import paths
that `legion-of-bom-core` can shell out to or wrap, rather than duplicating.

---

## 5. Fab design rules (`.kicad_dru`)

KiCad judges a board against whatever design rules the board declares. Ours
declared none, so `kicad-cli pcb drc` was checking against KiCad's built-in
defaults — not against what the fab can make. `crate::fab::jlcpcb_design_rules`
now emits a `.kicad_dru` beside the board in every fab package; `kicad-cli`
picks it up from the board's own directory automatically.

The numeric limits are **transcribed from JLCPCB's published capability**, not
copied from any of the files below, because none of them states a licence. These
are listed as cross-checks — read them when adding a rule or a process class,
and diff our numbers against theirs.

| Source | What it covers | License |
|---|---|---|
| [labtroll/KiCad-DesignRules](https://github.com/labtroll/KiCad-DesignRules) | JLCPCB, KiCad 7, one clean file — closest to our rule set | not stated |
| [Cimos/KiCad-CustomDesignRules](https://github.com/Cimos/KiCad-CustomDesignRules) | JLCPCB **and** PCBWay, KiCad 8, validated against a paired test board | not stated |
| [tinfever/KiCAD-Custom-DRC-Rules-for-JLCPCB-with-Unit-Tests](https://github.com/tinfever/KiCAD-Custom-DRC-Rules-for-JLCPCB-with-Unit-Tests) | Selectable 2-layer / 4-layer / 2oz, PASS/FAIL test board **per rule** | not stated |
| [ziteh/kicad-design-rules](https://github.com/ziteh/kicad-design-rules) | JLCPCB | not stated |

**Two things none of them can do**, both learned the hard way:

1. **No rule checks that a footprint is inside the board outline.** KiCad's
   constraint vocabulary cannot express it. A part moved 15.8 mm clear of the
   edge produces zero geometric violations. `crate::rules` `Tier::Physical` is
   the only check that sees this, and `lob fab` gates on it separately.
2. **Every rule that can match a non-copper item needs a layer condition.**
   Without one, `text_height` fires on `B.Fab`/`Cmts.User` annotations that are
   never manufactured and `silk_clearance` compares silkscreen against courtyard
   outlines. On one board that was the difference between "9 undersized texts and
   199 silkscreen overlaps" and the truth: 0 and 4.

## 6. Open item

- [ ] For every "license not confirmed" row above: a real license check
      (reading the repo's actual LICENSE file / provider's actual ToS) should
      happen before `legion-of-bom` treats any of these as a first-class,
      recommended source in documentation or tooling defaults — not before a
      person can use them, just before *we* vouch for them.

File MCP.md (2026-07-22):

# legion-of-bom — MCP Interface (MCP.md)

Status: DRAFT. Companion to DESIGN.md — this covers the agent-facing MCP surface,
not the core pipeline internals.

Design principle, stated plainly: an agent should be able to go from a prompt
("design me a modular crossfader in 1U, quality parts") all the way through
research, circuit definition, simulation, layout, and BOM — fully autonomously.
It should **not** be able to place a real order without a human. And nothing in
between should be allowed to *look* verified without actually being verified —
the LM13700-pinout-from-memory mistake earlier in this project is the failure
mode this whole doc is trying to structurally prevent, not just discourage.

---

## 1. Why datasheet reliability is the load-bearing problem

Everything else in this doc is plumbing. This part is the actual risk. An LLM
stating a pinout from training memory is indistinguishable, in tone, from an
LLM stating a pinout it actually read off a real datasheet — that's exactly
what went wrong when the slew limiter's LM13700 pins were drafted "from
memory" earlier in this project. The fix has to be structural, not a reminder
to "double check."

**Rule: circuit definition tools may not accept pin/parametric data from model
memory. Only from a fetched, cited source.**

### 1.1 Sourcing pinout/symbol data: structured libraries first, PDF as fallback
Two kinds of source exist, and they shouldn't be treated as equivalent:

- **Structured CAD library data** — DigiKey maintains an official, in-house
  KiCad library built by their own applications engineering team; JLCPCB's
  EasyEDA/LCSC library is reachable through the same Parts API already in use
  and has existing conversion tooling into KiCad format; SnapEDA/Ultra
  Librarian/SamacSys host a much larger but more variable-trust set (mixed
  professional and community-contributed content, with a verification badge
  worth checking). All of these already encode pin-number-to-pin-name mapping
  as structured data — someone had to get it right to use it in a schematic
  tool at all — which is a fundamentally better extraction source than parsing
  it back out of PDF prose.
- **PDF datasheets** — still the source of truth for absolute max ratings and
  anything not captured in a symbol file, and useful as a cross-check against
  a CAD library entry, but not the primary pinout-extraction path when a
  structured library entry already exists.

**Trust order for `fetch_datasheet` / pinout extraction:** distributor-official
library (DigiKey KiCad library, JLCPCB/EasyEDA) → broader CAD library
(SnapEDA/Ultra Librarian, checking verification status) → PDF datasheet
extraction as the fallback when no library entry exists yet, and always as a
cross-check source for ratings regardless of which library was used for the
pinout. The datasheet URL itself, when PDF parsing is needed, still comes only
from a distributor API record (JLCPCB/Mouser/DigiKey), never a general web
search — that part of the rule doesn't change.

### 1.2 Fetch and extract, don't recall
`fetch_datasheet` (Section 2) retrieves structured pin/footprint data from a
CAD library per the trust order above, or extracts text/tables from a PDF
datasheet when no library entry exists — pin assignment tables, absolute max
ratings, package info. Either way, this is a real fetch-and-parse operation,
not a cached "the model already knows this part" shortcut. Extracted data is
written to a **global, Dolt-backed parts library** (not a per-project git
sidecar file) — this is **core `legion-of-bom-core` architecture, not an
MCP-only construct** (see Section 1.4 below): once a part is verified, it's
verified for every future project and every entry point (CLI, MCP, future web
UI alike), not re-verified per repo or per interface. This mirrors the
Dolt-vs-git storage split already decided in DESIGN.md Section 2.6: circuit
definitions are project-specific and belong in git; verified part data is
cross-project structured data that needs to be queried and reused, which is
exactly what Dolt is for. Versioned via Dolt's refs the same way everything
else is — each verification event is a commit, diffable and revertable like
any other change in the system.

**Proposed schema (Dolt tables):**
```sql
CREATE TABLE parts (
  id INT PRIMARY KEY,
  mpn VARCHAR(64) NOT NULL,          -- manufacturer part number, canonical key
  manufacturer VARCHAR(128),
  datasheet_url TEXT NOT NULL,       -- from distributor API, never free-form search
  fetched_at DATETIME,
  verified_by_human BOOLEAN DEFAULT FALSE,
  verified_at DATETIME,
  verified_by VARCHAR(64)
);

CREATE TABLE part_pins (
  part_id INT REFERENCES parts(id),
  pin_number VARCHAR(8),
  pin_name VARCHAR(64),
  cited_page INT                     -- page in the source datasheet this came from
);

CREATE TABLE part_ratings (
  part_id INT REFERENCES parts(id),
  rating_name VARCHAR(64),           -- e.g. "Vcc_max", "Iabc_max"
  value TEXT,
  unit VARCHAR(16),
  cited_page INT
);
```
A circuit's SKiDL definition references parts by `mpn`, and `define_circuit`
looks up verified data from this global table rather than any per-project
file. First use of a new part still triggers the one-time human verification
step (Section 3); every subsequent project reusing that MPN reads
already-verified data for free.

### 1.3 Every extracted fact carries a[118;1:3u citation, not just a value
Every row in `part_pins` and `part_ratings` carries a `cited_page` back to the
source datasheet — never a bare value with no traceable origin. `parts.
verified_by_human` starts `FALSE` on every new part row. This is the field
the "resolved open questions" gate (Section 3) actually checks — not "did we
fetch a datasheet" but "did a human confirm the extraction was read
correctly."

### 1.4 This is core `legion-of-bom-core` architecture, not an MCP-only construct
This is worth stating plainly because it changes where the enforcement actually
lives: the parts library, the `verified_by_human` gate, and the checks that
block `layout`/`generate_bom` are **pipeline-core behavior**, not something
bolted onto the MCP tool wrapper. An MCP tool call and a direct `lob layout`
CLI invocation hit the exact same check inside `legion-of-bom-core` — the MCP
tool doesn't independently re-implement the gate, it just inherits it by
calling into the same library (per DESIGN.md Section 2.2's "CLI and web share
one core" principle). Practical consequence: DESIGN.md's Validation Layer
(Section 4) and BOM & PCBA Pipeline (Section 9) need this gate specified
there too, not just here — MCP.md describes the *agent-facing* shape of a
check that has to exist regardless of who or what is driving the pipeline.

### 1.5 Cross-check on anything safety/money-relevant
For pin assignments and absolute max ratings specifically (the two categories
where an error causes physical damage or a bad board respin), the extraction
tool should attempt to fetch from **two independent sources** where possible
(e.g. a distributor-official CAD library entry and the manufacturer's own PDF)
and flag a mismatch rather than silently picking one. Parametric data that's
just "nice to know" (typical values, graphs) doesn't need this — the gate is
proportional to what breaks if it's wrong.

### 1.6 What this does NOT solve
This makes pinout/rating *extraction* reliable. It does not make *topology
selection* reliable — an agent can correctly extract a real LM13700 pinout and
still put it in a bad circuit. That's what `research_topology`'s citation
requirement (Section 2) and the human-in-the-loop sim review are for —
datasheet reliability and circuit correctness are separate problems.

---

## 2. MCP Tools

All tools run against the local `legion-of-bom-core` (Section 2.2 of
DESIGN.md) — this is the local-first MCP server, not a hosted SaaS surface.

| Tool | Purpose | Gated? |
|---|---|---|
| `create_project` | Scaffold a new board repo from a `PanelProfile` (format: Eurorack/Pedal/Rack/Desktop) | No |
| `research_topology` | Search for real reference circuits for a given function (e.g. "crossfader"); returns candidate topologies + citations | No |
| `search_part` | Resolve a part number or functional need to distributor records (JLCPCB/Mouser/DigiKey), including datasheet URL | No |
| `fetch_datasheet` | Fetch structured pin/rating data (CAD library or PDF fallback, per Section 1.1) into the global parts library | No |
| `define_circuit` | Write/update the SKiDL circuit definition, referencing verified part data (not model memory) | No |
| `validate` | Run ERC | No |
| `simulate` | Run ngspice / PedalKernel simulation | No |
| `layout` | Run the iterative layout loop (DESIGN.md Section 6) | **Yes — enforced by `legion-of-bom-core` (Section 1.4), same for CLI and MCP: requires open-questions checklist clear + all used parts `verified_by_human = TRUE`** |
| `generate_bom` | Generate BOM/CPL with live pricing/stock from JLCPCB, Mouser, DigiKey APIs | **Yes — same core-enforced gate as `layout`** |
| `submit_for_approval` | Package design + BOM + cost + sourcing status into a human-reviewable summary | No (this *is* the human touchpoint) |
| `place_order` | Actually submit a PCBA/parts order | **Human-only. Not agent-callable. No MCP tool exists for this — it's a manual action outside the MCP surface entirely.** |

### 2.1 On `place_order` specifically
This isn't a permissions flag that could theoretically be toggled — there is
no `place_order` MCP tool. If we ever build one, that's a deliberate,
separate decision, not a default the agent surface grows into by accident.

### 2.2 The verification gate, concretely
Before `layout` or `generate_bom` run — whether invoked via MCP or the `lob`
CLI directly, since this lives in `legion-of-bom-core` per Section 1.4, not
in the MCP wrapper — the check confirms:
- Every part referenced in the circuit has a `parts` row with
  `verified_by_human = TRUE` in the global library
- The circuit's open-questions checklist (per the pattern in
  `slew-limiter-circuit.md`) has no unresolved items
If either check fails, the tool returns the specific blocking items rather
than running anyway — the agent's job at that point is to either resolve them
(re-fetch, ask you to verify) or surface them to you, not proceed.

---

## 3. Human verification step (how `verified_by_human` actually gets set)

A lightweight review, not a full datasheet read-through: the agent presents
the extracted pinout/ratings table plus a link/citation to the source page,
you confirm or correct it once per part (not once per circuit — a part
verified in one project stays verified for reuse elsewhere, per the global
Dolt-backed parts library in Section 1.2). This is the same shape as the
slew limiter's open-questions checklist, just tool-enforced instead of
doc-enforced.

---

## 4. Example flow: "design me a crossfader in 1U, quality parts"

1. `create_project` — new repo, Eurorack `PanelProfile`, mode: Analog
2. `research_topology("crossfader")` — returns 2-3 real reference topologies
   (e.g. dual-VCA constant-power crossfade designs) with citations
3. You pick one (or the agent proposes its recommendation, you confirm)
4. `search_part` + `fetch_datasheet` for each part the chosen topology needs
5. **You verify pinouts/ratings once per new part** (existing parts like
   TL072 may already be verified from earlier circuits)
6. `define_circuit` — SKiDL written against verified data from the global
   parts library
7. `validate`, `simulate` — iterate as needed
8. `layout` — gate passes (all parts verified, checklist clear), iterative
   loop runs
9. `generate_bom` — real pricing/stock pulled
10. `submit_for_approval` — you get a real summary: schematic, sim results,
    layout, BOM with actual cost
11. You place the order yourself. Not a tool call.

Steps 1–10 are genuinely "no sweat" for you — research, design, sim, layout,
and costing all happen without you touching a keyboard except the one-time
per-part verification in step 5. Step 11 stays yours on purpose.

---

## Open questions

- [ ] Where does `research_topology` search — general web search with citation
      requirements, or a curated set of trusted sources (manufacturer app
      notes, established module-design references)? Unbounded web search risks
      pulling in bad reference designs with the same false-confidence problem
      as datasheet recall.
- [ ] What happens when `research_topology` can't find a good reference for a
      genuinely novel circuit — does the agent refuse, or flag lower
      confidence and proceed with more scrutiny requested at the verification
      step?
- [x] **Open-core licensing shape — resolved.** Public repo
      (`FuturePresentLabs/legion-of-bom`) stays AGPLv3 with a CLA required
      for contributions. The CLA means contributions are licensed/assigned
      back to Future Present Labs, so — as full copyright holder — the
      company isn't bound by AGPL's terms the way an external fork would be,
      and can dual-license the same codebase commercially for the paid tier
      (validation libraries, official distributor integrations) without
      splitting into a separate closed repo. Same pattern GitLab/MongoDB/
      Mattermost use: AGPL protects the community edition from silent
      competing forks, CLA preserves the company's ability to sell a
      proprietary version of the same code. No repo split needed.

---

MCP tools for BTS creatives

All of these are thin wrappers over commands the pipeline already uses or was going to need — nothing here is new engineering, mostly new call sites:

export_schematic_image — kicad-cli sch export svg (or pdf), headless, no GUI dependency. Clean schematic shots for free.
export_pcb_layout_image — kicad-cli pcb export svg, with a layer-set param (e.g. silkscreen+copper for a "clean" shot, all layers for an "X-ray" shot). Same export path as gerbers, just SVG instead of Gerber.
export_pcb_3d_render — kicad-cli pcb export step, then either (a) screenshot KiCad's own 3D viewer over the existing IPC connection you already use for layout/panels — fastest, lowest quality — or (b) feed the STEP into a headless Blender render for a real hero shot. Start with (a), upgrade later.
export_gerber_preview — gerbers aren't visually pretty on their own; render them to a bitmap via something like tracespace/pcb-stackup (JS) or gerbv (CLI) for a "here's the copper" shot.
export_bom_table_image — the BOM epic already produces a table; a simple HTML→PNG render (headless Chromium, or even just styled markdown → image) turns that into something postable.
export_panel_preview — the DXF export (7.1) already exists for fab ordering; adding the SVG sibling (7.2, currently deprioritized since fab vendors only want DXF) is now worth bumping up specifically for this — it's the one that makes the front-panel art actually look good in a shot, which DXF alone doesn't buy you.
The agent + skill

creative-bts-package as a skill, driven by an agent that:

Takes a project repo path + git ref (so a "package" is tied to a specific commit/revision, consistent with how the pipeline already treats attempts as commits)
Calls the export tools above in sequence, writes outputs to a dated folder
Diffs against the last package's git ref to know what actually changed (new part, routing revision, panel tweak) — that diff is the natural hook for autolayout's voiceover script, so the agent can draft a one-paragraph "what's new" caption stub alongside the images instead of you writing it from scratch each time

That's genuinely not a big lift — it's an orchestration skill over exports that mostly already exist or are single kicad-cli calls away, plus a git diff you get for free because everything's already version-controlled. The only real new work is the SVG panel export (bumping 7.2 forward) and picking option 1 vs. 2 for the 3D render.

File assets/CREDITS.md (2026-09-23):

# Credits & Licenses — vendored component assets

`assets/` vendors a real, sourced set of panel-component footprints and 3D
meshes for hardware KiCad's own stock libraries don't cover well (Eurorack-
style 3.5mm jacks, 9mm pots, panel LEDs, slide switches). Both upstream
sources are license-clean for redistribution; this file records attribution
and license terms so the set can be re-fetched or extended later without
re-deriving provenance from scratch.

Brought in via the same vendoring this project's other author (Avery Wagar)
already did once for a private, unpublished workspace — re-vendored here
directly from the original upstream projects' own terms, not from that
workspace (which carries its own, separate licensing and is not a source of
truth for reuse).

## Panel footprints — 4ms-kicad-lib (Unlicense / public domain)

`assets/footprints/Eurorack_4ms.pretty/*.kicad_mod` are from **4ms-kicad-lib**
(`footprints-legacy/4ms-legacy-footprints.pretty`), released under the
**Unlicense** (public domain dedication). No attribution required; recorded
here for provenance.

Vendored footprints:

- `PJ301M-12.kicad_mod` — Thonkiconn / PJ301BM 3.5mm jack socket
- `POT-9MM-ALPHA.kicad_mod` — Alpha 9mm vertical pot, smooth shaft
- `POT-9MM-KNURL.kicad_mod` — Alpha 9mm vertical pot, knurled shaft
- `LED-3MM-SQUARE-ANODE.kicad_mod` — 3mm square LED
- `Slide_Switch_SS22D06-G6-H_Runrun.kicad_mod` — SS22D06 slide switch
- `RGB_ROTARY_ENCODER.kicad_mod` — RGB rotary encoder
- `POT-SLIDER-LED-ALPHA-RA2045F-20.kicad_mod` — Alpha RA2045F 20mm slide pot w/ LED

To re-fetch: `https://github.com/4ms/4ms-kicad-lib`, path
`footprints-legacy/4ms-legacy-footprints.pretty/`.

## 3D meshes — jolin-components (CC-BY 4.0) — ATTRIBUTION REQUIRED

`assets/meshes/jolin/{glb,step}/*` are from the **jolin-components** library
by **jolin**, licensed **Creative Commons Attribution 4.0 (CC-BY 4.0)**.

> 3D models © jolin (jolin-components), licensed under CC-BY 4.0.
> https://creativecommons.org/licenses/by/4.0/

Vendored meshes:

| File (stem) | Part |
|---|---|
| `jack_socket_PJ301BM_3.5mm` | Thonkiconn / PJ301BM 3.5mm jack socket |
| `pot_RD901F_6.35mm_shaft_alpha_9mm_vertical` | Alpha RD901F 9mm vertical pot, 6.35mm shaft |
| `pot_RD901F_T18_shaft_alpha_9mm_vertical` | Alpha RD901F 9mm vertical pot, T18 splined shaft |
| `knob_KN8F_6.35mm_shaft` | KN8F knob cap, 6.35mm shaft |
| `knob_RB671_Rogan_6.35mm_shaft` | Rogan RB671 knob cap, 6.35mm shaft |
| `LED_square_3mm_red` | 3mm square LED |
| `switch_slide_onoff_SS12D00` | SS12D00 slide switch |
| `fader_Bourns_45mm` | Bourns 45mm fader |

To re-fetch: search for `jolin-components` (jolin); confirm the CC-BY 4.0
terms are unchanged before re-vendoring, since attribution license terms can
be revised by the upstream author.

## Real Eurorack physical constants (public spec, not third-party IP)

Standard Eurorack dimensions, for reference against
[`crate::panel::BuiltinCutouts`](../crates/core/src/panel.rs) and
[`crate::pedal_panel::PedalCutouts`](../crates/core/src/pedal_panel.rs):

- `HP_MM = 5.08` — one horizontal pitch unit
- `EURORACK_HEIGHT_MM = 128.5` — standard 3U panel height

These are industry-standard physical facts (Doepfer's own A-100 spec), not
anyone's IP — no license question, just recorded here since they're the
same numbers this vendored data was cross-validated against.

## Status

Vendored for provenance and future use; not yet wired into
[`BuiltinCutouts`](../crates/core/src/panel.rs)'s hole-size table or exposed
via [`house_footprint_dir()`](../crates/core/src/parts.rs) as a built-in
fallback footprint library. That integration is tracked as follow-up work,
not done here.

## Not vendored here, and why

Real per-module hardware data for specific Eurorack modules (e.g. Mutable
Instruments Plaits/Marbles panel layouts) is **not** part of this set. That
data is real and does exist (in a separate, unpublished circuits repo, kept
deliberately isolated there), but it's licensed CC-BY-SA-3.0 (share-alike)
from its own upstream (`pichenettes/eurorack`) — folding share-alike-licensed
content into this AGPL-3.0-or-later repo would require this repo (or at
least the affected files) to carry compatible share-alike terms, which is a
real licensing decision, not a mechanical copy. If real per-module panel
data is wanted here later, follow the same isolation pattern (its own
directory, its own attribution file, explicit upstream credit) rather than
merging it into this general-purpose asset set.

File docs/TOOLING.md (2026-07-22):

# Toolchain (Phase 0)

The Phase 0 pipeline shells out to external tools. This is the pinned, verified
set the loop runs against, and how `lob` locates each one. Run `lob doctor` to
check your machine against this list.

| Tool | Role | Required? | Version verified | Discovery |
|---|---|---|---|---|
| **ngspice** | Simulation (AC sweep) — DESIGN.md §5 | Yes (loop is sim-verified) | 45.2 | `PATH` |
| **SKiDL** (Python) | Circuit definition → netlist + ERC — DESIGN.md §3–4 | Yes | 2.2.3 | `.venv/bin/python`, else `python3` on `PATH` |
| **KiCad symbol libs** | SKiDL resolves `Device:R` etc. against these | Yes | KiCad 10 libs | `KICAD9_SYMBOL_DIR`, else macOS default path |
| **kicad-cli** | Layout / board output — DESIGN.md §6 | No (Phase 0 stretch) | 10.0.0 | `PATH`, else macOS app bundle |

## How `lob` finds tools

`PATH` first, then a known fallback (the macOS KiCad app bundle for `kicad-cli`).
The tool table lives in `legion-of-bom-core::tools` so the CLI, the future MCP
server, and the pipeline stages all discover tools the same way. Stages that
can't find a required tool fail gracefully — they never panic.

## Notes on the pinned versions

- **SKiDL 2.2.3 defaults to the `kicad9` backend**, so it reads symbol libraries
  from `KICAD9_SYMBOL_DIR` specifically (not `KICAD_SYMBOL_DIR` or `KICAD8_*`).
  KiCad 10's `.kicad_sym` format is compatible, so pointing `KICAD9_SYMBOL_DIR`
  at KiCad 10's libraries works.
- `kicad-cli` is **not on `PATH`** in a default macOS KiCad install; it lives at
  `/Applications/KiCad/KiCad.app/Contents/MacOS/kicad-cli`. `lob` falls back to
  that path automatically.
- The RC demo emits **0 ERC errors**. It does produce 2 ERC *warnings*
  (single-pin nets on the filter's open `IN`/`GND` ports) — expected for a
  two-port block; the simulation stage adds the AC source/ground testbench.

## Setup

```bash
# 1. Python venv with SKiDL (pinned in requirements.txt)
python3 -m venv .venv
.venv/bin/pip install -r requirements.txt

# 2. Point SKiDL at KiCad's symbol libraries (macOS default shown)
export KICAD9_SYMBOL_DIR="/Applications/KiCad/KiCad.app/Contents/SharedSupport/symbols"

# 3. ngspice (macOS)
brew install ngspice

# 4. Verify
cargo run -p legion-of-bom-cli -- doctor
```

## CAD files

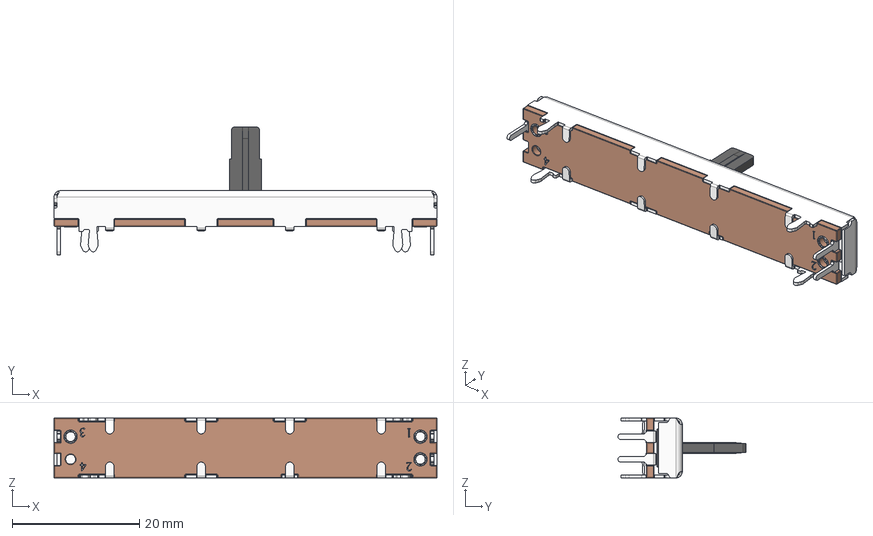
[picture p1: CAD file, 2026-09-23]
assets/meshes/jolin/step/fader_Bourns_45mm.step
60.1 x 20.1 x 9.40 mm

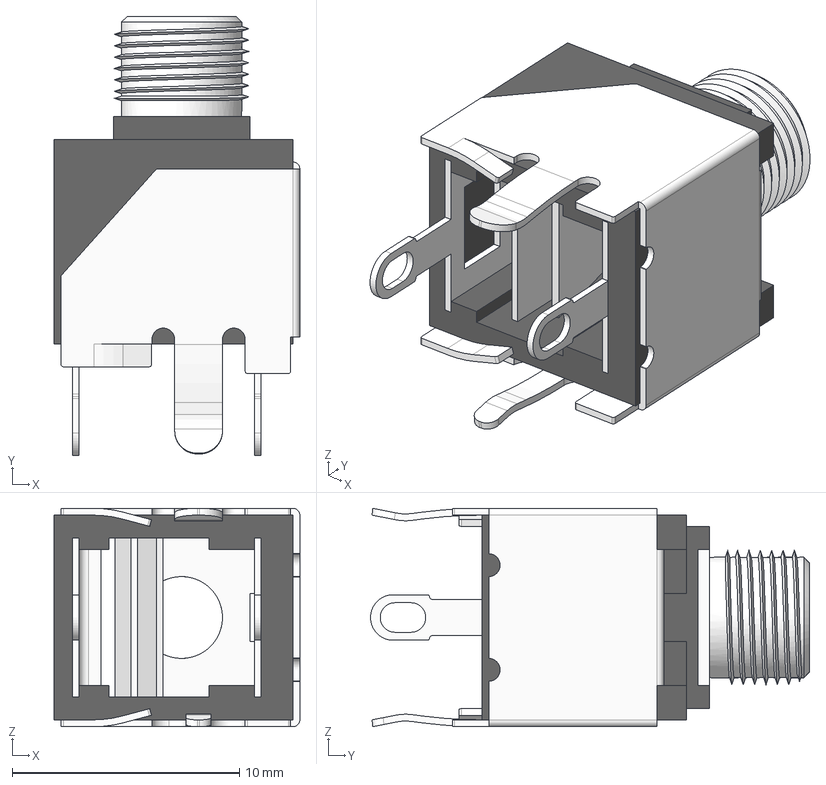
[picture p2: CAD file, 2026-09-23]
assets/meshes/jolin/step/jack_socket_PJ301BM_3.5mm.step
10.8 x 19.3 x 9.60 mm

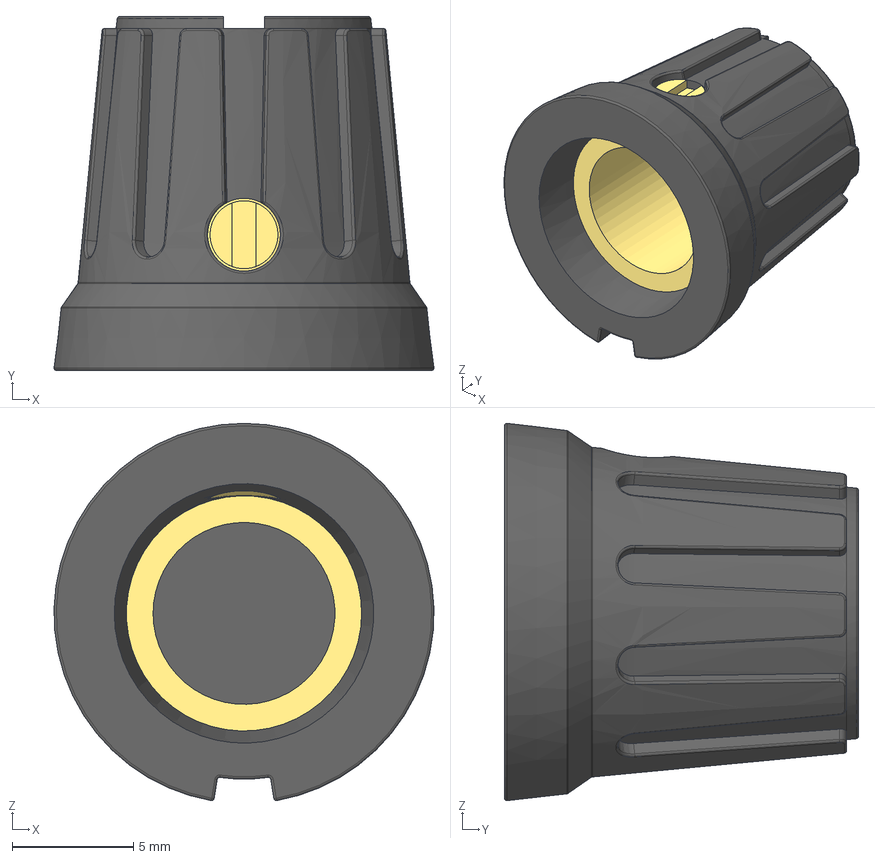
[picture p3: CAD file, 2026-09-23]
assets/meshes/jolin/step/knob_KN8F_6.35mm_shaft.step
15.7 x 14.6 x 15.6 mm

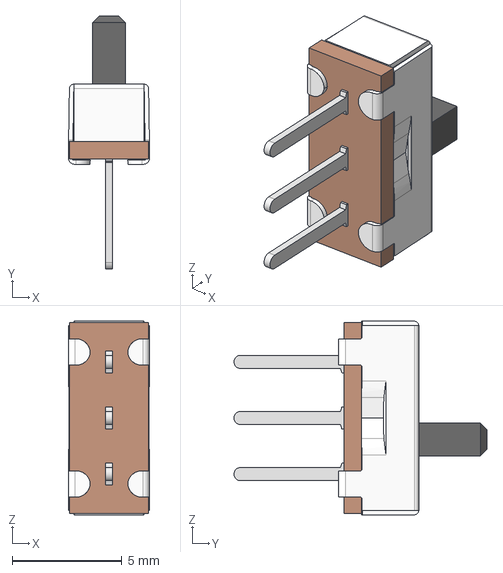
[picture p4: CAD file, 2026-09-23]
assets/meshes/jolin/step/switch_slide_onoff_SS12D00.step
3.70 x 11.5 x 8.80 mm

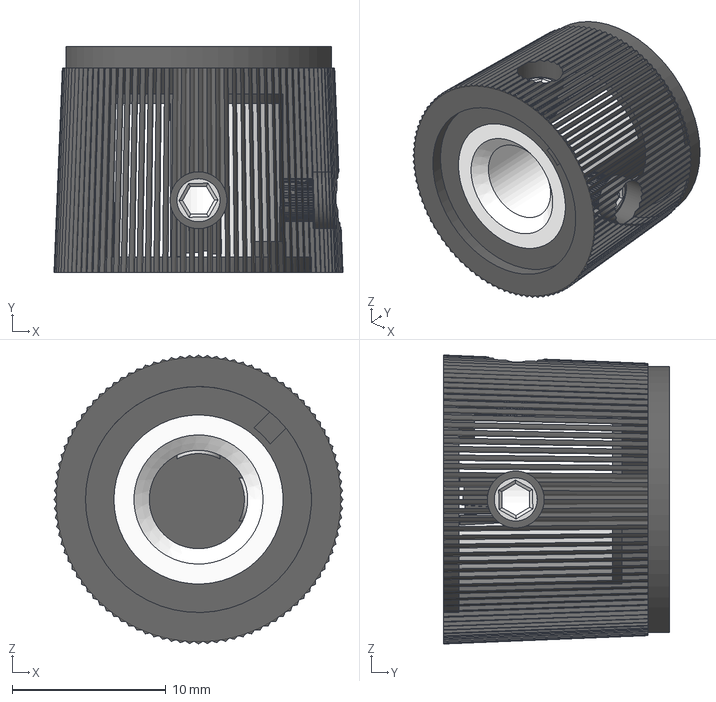
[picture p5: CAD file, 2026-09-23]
assets/meshes/jolin/step/knob_RB671_Rogan_6.35mm_shaft.step
18.8 x 14.7 x 18.8 mm

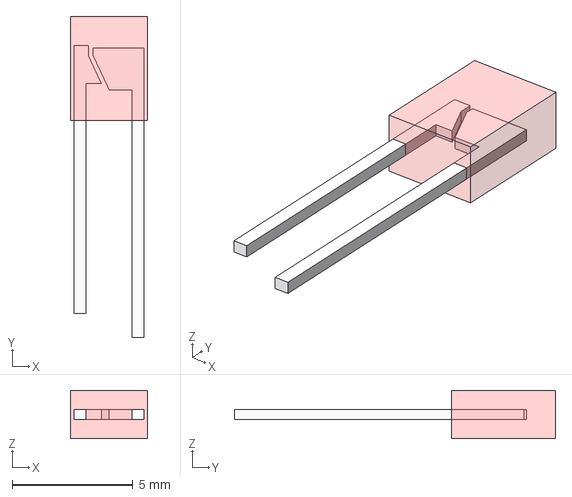
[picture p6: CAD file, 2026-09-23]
assets/meshes/jolin/step/LED_square_3mm_red.step
3.20 x 13.3 x 2.00 mm

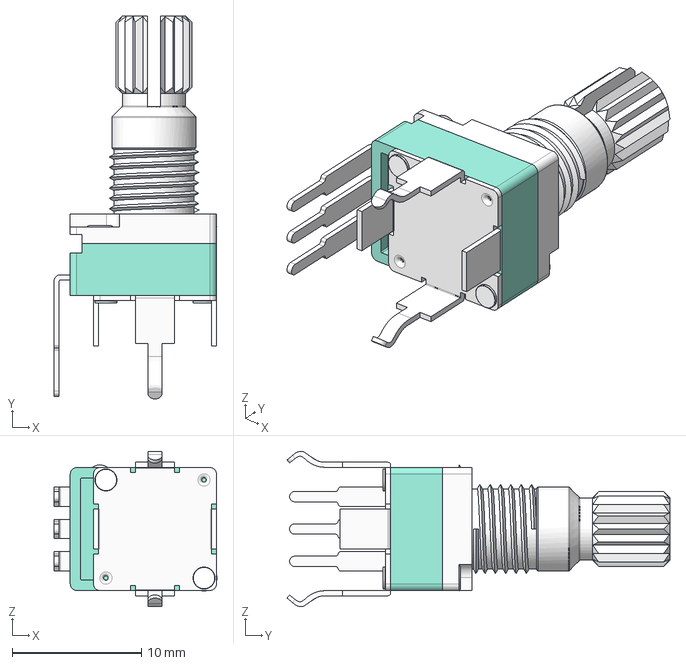
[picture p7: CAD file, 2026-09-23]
assets/meshes/jolin/step/pot_RD901F_T18_shaft_alpha_9mm_vertical.step
12.6 x 29.6 x 12.0 mm

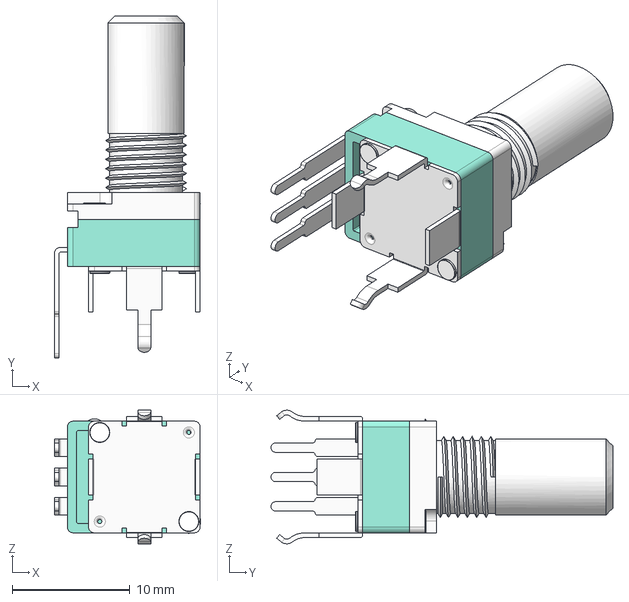
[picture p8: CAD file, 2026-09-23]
assets/meshes/jolin/step/pot_RD901F_6.35mm_shaft_alpha_9mm_vertical.step
12.4 x 29.1 x 11.4 mm

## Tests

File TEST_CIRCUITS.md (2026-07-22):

# Phase 0 Test Circuits — legion-of-bom

Purpose: two textbook circuits used to validate the full legion-of-bom pipeline
(SKiDL → ERC → ngspice sim → KiCad layout → BOM/CPL) against known-good, hand-
calculable answers before any real product design goes through it.
These are deliberately boring — the goal is a trustworthy answer key, not an
interesting circuit.

---

## Circuit 1: RC Low-Pass Filter

**Topology:** single-pole passive RC low-pass. Input → R1 → output node → C1 → GND.

**Components:**
| Ref | Part | Value | Notes |
|-----|---|---|---|
| R1  | Resistor | 1.6 kΩ | E24 standard value |
| C1  | Capacitor | 100 nF | C0G/film preferred for predictable sim |

**Target spec:**
- Cutoff frequency (−3dB point): `fc = 1 / (2π·R·C)` = 1 / (2π × 1600 × 100e-9) ≈ **995 Hz**
- No active parts, no power rails — simplest possible pipeline exercise.

**Validation criteria:**
- ERC: passes trivially (two-terminal passive network, no unconnected pins possible
  in this topology)
- ngspice AC analysis: sweep 1 Hz–100 kHz (decade sweep, 20 pts/decade), confirm
  −3dB point falls at 995 Hz ± 5% and rolloff is −20dB/decade above fc (first-order
  response)
- BOM: exactly 2 line items (R1, C1), both basic-library parts on JLCPCB — this
  circuit should never hit an extended-parts fee
- Layout: 2 footprints, no routing complexity — good test that DFM/panel stages
  don't choke on a near-trivial board

---

## Circuit 2: Non-Inverting Op-Amp Gain Stage

**Topology:** single op-amp, non-inverting configuration. Signal into +in. Output
fed back through R2 to −in; R1 from −in to GND sets the gain ratio.

**Components:**
| Ref | Part | Value | Notes |
|-----|---|---|---|
| U1  | Op-amp | TL072 (use channel A only) | Same part already in the slew-limiter buffer stages — reuse familiarity |
| R1  | Resistor | 1.0 kΩ | Gain-setting, −in to GND |
| R2  | Resistor | 10 kΩ | Feedback, output to −in |
| C1  | Capacitor | 100 nF | Local decoupling, V+ to GND |
| C2  | Capacitor | 100 nF | Local decoupling, V− to GND |

**Power:** dual ±12V rails (V+, V−, GND) — matches your existing Eurorack bus
convention even though this isn't a Eurorack module, so the same power-header
habits and decoupling-cap-at-the-pin discipline from Section on grounding
mistakes gets exercised here too.

**Target spec:**
- Gain: `Av = 1 + R2/R1` = 1 + (10k/1k) = **11** (20.8 dB)
- DC-coupled, no input/output blocking caps — deliberately simple, not meant to be
  audio-production-ready

**Validation criteria:**
- ERC: passes; also a first real test of "does ERC catch a missing power
  connection" — worth deliberately breaking the power net once in testing to
  confirm ERC actually flags it
- ngspice AC analysis: confirm flat gain of 11 (20.8 dB) across the op-amp's usable
  bandwidth, matches hand calc within a few %
- BOM: 5 line items (U1, R1, R2, C1, C2) — first circuit with a real IC in the BOM/
  CPL step and first real JLCPCB parts-catalog stock check
- Layout: first test of "decoupling cap physically close to the IC power pin" per
  the grounding/routing discipline we discussed for the phono pre — good low-
  stakes place to build that layout habit

---

## Open items before handing to SKiDL/Claude Code

- [ ] Confirm TL072 footprint choice (SOIC-8 vs DIP-8) — SOIC-8 assumed above to
      match JLCPCB SMT assembly flow; flag if DIP-8 hand-soldering is preferred
      for these throwaway test boards
- [ ] Confirm whether Circuit 2 should get eurorack-style jacks (for realism) or
      simple test points (simpler BOM, faster to lay out) — test points recommended
      for Phase 0 since these aren't meant to ship as products

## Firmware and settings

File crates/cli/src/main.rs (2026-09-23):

//! `lob` â the legion-of-bom command-line interface.
//!
//! A thin wrapper over `legion-of-bom-core`. The `run` subcommand runs the full
//! Phase 0 pipeline â SKiDL run â parse â validate â simulate â verify â BOM â
//! and reports per-stage pass/fail, exiting non-zero on any failure.

mod doctor;

use std::path::{Path, PathBuf};
use std::process::ExitCode;

use anyhow::{Context, Result};
use clap::{Parser, Subcommand};
use legion_of_bom_core::family;
use legion_of_bom_core::skidl::{kicad_footprint_dir, kicad_symbol_dir};
use legion_of_bom_core::{
    analytic_check, build_facts, build_guide_with, default_image_cache_dir,
    default_panel_orders_dir, default_parts_dir, derive_panel, derive_panel_for, embed_source,
    eurorack_trial_build, export_board_glb, export_cpl, export_gerbers, fetch_from_jlcpcb,
    fetch_from_kicad, free_outline_template, generate_board_artifacts, generate_bom,
    generate_fuzz_chain, guide, guide_to_html, guide_to_pdf, jlc_assembly_bom, jlcpcb_design_rules,
    kicad_cli_path, min_panel_hp_for, minimum_hp, minimum_routable_hp, package_key,
    panel_from_board, panel_to_dxf, panel_to_kicad_pcb, parse_netlist_file, part_kind_of,
    photo_source, plan_repair, png_to_jpeg, render_board_png, render_spec_text, rules, run_drc,
    run_layout_loop, schematic_to_svg, simulate_ac, simulate_tran, simulate_tran_drive,
    suggest_by_keyword, suggest_mpns, svg_to_pdf_bytes, validate_erc, value_key, zip_dir,
    ArtifactKind, ArtifactStatus, BoardOptions, BoardPng, BomLine, BuildCopy, BuiltinCutouts,
    CircuitSource, EnclosureSize, EurorackPlacer, Finding, FuzzConstraints, GuideOptions, HpSearch,
    JlcpcbClient, KitType, LayoutLoop, LayoutMode, Logo, Manifest, MouserClient, PanelFile,
    PanelFormat, PanelOrders, PartRecord, PartResolution, PartsLibrary, PipelineReport,
    PlacementFile, Populate, ProjectView, Quality, Repair, ResolutionStatus, SeededPlacer,
    Severity, SilkLegend, SimConfig, SkidlRunner, SourcingClients, StageOutcome, TranAnalysis,
    TranDrive,
};

/// legion-of-bom: circuit-as-code in, manufacturing-ready outputs out.
#[derive(Debug, Parser)]
#[command(name = "lob", version, about)]
struct Cli {
    /// Increase log verbosity: -v = debug, -vv = trace.
    #[arg(short, long, action = clap::ArgAction::Count, global = true)]
    verbose: u8,

    #[command(subcommand)]
    command: Command,
}

#[derive(Debug, Subcommand)]
enum Command {
    /// Run the pipeline on a circuit definition.
    Run {
        /// Path to the circuit definition (e.g. a SKiDL script).
        circuit: PathBuf,
    },
    /// List the circuits declared in this repo's lob.toml.
    Circuits,
    /// Build a circuit's full artifact set (guide + Visual BOM + fab package), or
    /// every circuit in the repo when no name is given.
    Build {
        /// Circuit name from lob.toml; omit to build all circuits.
        circuit: Option<String>,
    },
    /// Show each circuit's build state â which artifacts exist and whether they
    /// are stale relative to the source + manifest. No network.
    Status,
    /// Serve the local web dashboard (localhost, no auth) for this repo â the
    /// read-only Forestry-style viewer over the same core.
    Serve {
        /// Address to bind (host:port).
        #[arg(long, default_value = "127.0.0.1:8080")]
        bind: String,
    },
    /// Check that the external toolchain (ngspice, kicad-cli, SKiDL) is available.
    Doctor,
    /// Inspect and edit the global, SQLite-backed parts library.
    Parts {
        #[command(subcommand)]
        action: PartsCmd,
    },
    /// Generate a BOM for a circuit, optionally priced live from Mouser.
    Bom {
        /// Path to the circuit definition (e.g. a SKiDL script).
        circuit: PathBuf,
        /// Look up live unit price + stock from Mouser (needs MOUSER_API_KEY).
        #[arg(long)]
        price: bool,
        /// Also write the BOM CSV to this path.
        #[arg(long)]
        out: Option<PathBuf>,
        /// Also write a Visual BOM (HTML): a part photo per line (Thonk, then
        /// EasyEDA/LCSC â both keyless), with through-hole resistors shown as
        /// their color code.
        #[arg(long)]
        visual: bool,
        /// Keep surface-mount parts on the sorting sheet. Off by default: on a
        /// mixed kit the fab has already reflowed them, so a cell for one is a
        /// cell the builder never uses.
        #[arg(long)]
        smd: bool,
    },
    /// Generate a .kicad_pcb board file (footprints placed + routed) from a circuit.
    Board {
        /// Path to the circuit definition (e.g. a SKiDL script).
        circuit: PathBuf,
        /// Write the board here (default: out/<name>/<name>.kicad_pcb).
        #[arg(long)]
        out: Option<PathBuf>,
        /// Eurorack panel spec (TOML): anchor jacks/pots to its cutouts and size
        /// the board to the panel (vertical 3U) instead of a bounding-box strip.
        #[arg(long)]
        panel: Option<PathBuf>,
        /// Layout cost-function mode (only affects the panel-anchored loop):
        /// analog | digital | mixed.
        #[arg(long, default_value = LAYOUT_MODE)]
        mode: String,
        /// Iterative layout attempts over a panel board (0 = one-shot placement).
        #[arg(long, default_value_t = 6)]
        iterations: usize,
        /// Brand logo SVG to render on the back silk (bottom-centre).
        #[arg(long)]
        logo: Option<PathBuf>,
        /// Also write a combined, named, colored 3D scene (.glb) of the
        /// placed board â for an external model viewer, never a rendered
        /// image. See `legion_of_bom_core::export_board_glb`.
        #[arg(long)]
        model: Option<PathBuf>,
    },
    /// Render a readable schematic diagram (symbols + routed nets) from a
    /// circuit â SVG for viewing/iterating, PDF for a shareable final export.
    /// At least one of --svg/--pdf is required.
    Diagram {
        /// Path to the circuit definition (e.g. a SKiDL script).
        circuit: PathBuf,
        /// Write the diagram as SVG here.
        #[arg(long)]
        svg: Option<PathBuf>,
        /// Write the diagram as PDF here (one page, sized to the diagram).
        #[arg(long)]
        pdf: Option<PathBuf>,
    },
    /// Drive a sine sweep into a circuit's recognized input net and measure
    /// gain compression / flat-topping â "does this circuit actually clip
    /// like a fuzz" as a measured SPICE claim, not a schematic read. Exits
    /// non-zero only if the measurement itself couldn't run (SKiDL/netlist
    /// failure, or no recognizable input net) â a low/uninteresting
    /// flat-top is still exit 0, since "it doesn't clip at this drive
    /// level" is a valid, successfully-measured answer. Threshold
    /// pass/fail against a task's rubric is the caller's job (see
    /// PCBBench's `Check::SpiceClips`), not this command's.
    ScopeProbe {
        /// Path to the circuit definition (e.g. a SKiDL script).
        circuit: PathBuf,
        /// Override which net to drive (default: SimConfig::infer's guess).
        #[arg(long)]
        input_net_hint: Option<String>,
        /// Sweep drive frequency (Hz).
        #[arg(long, default_value_t = 200.0)]
        freq_hz: f64,
        /// Smallest drive amplitude, peak volts.
        #[arg(long, default_value_t = 0.005)]
        min_amplitude: f64,
        /// Largest drive amplitude, peak volts.
        #[arg(long, default_value_t = 1.0)]
        max_amplitude: f64,
        /// Sweep points between min and max amplitude (log-spaced).
        #[arg(long, default_value_t = 8)]
        steps: usize,
        /// Write the measurement report here as JSON.
        #[arg(long)]
        out: PathBuf,
    },
    /// Run DRC on a .kicad_pcb and report violations (the layout loop's check step).
    Drc {
        /// Path to the board file to check.
        board: PathBuf,
    },
    /// Build a DRC-gated manufacturing package (Gerbers + drill + JLCPCB CPL + BOM).
    Fab {
        /// Path to the circuit definition (e.g. a SKiDL script).
        circuit: PathBuf,
        /// Package directory (default: out/<name>/fab).
        #[arg(long)]
        out: Option<PathBuf>,
        /// Eurorack panel spec (TOML): build the vertical panel-anchored board.
        #[arg(long)]
        panel: Option<PathBuf>,
        /// Layout cost-function mode: analog | digital | mixed.
        #[arg(long, default_value = LAYOUT_MODE)]
        mode: String,
        /// Iterative layout attempts over a panel board (0 = one-shot placement).
        #[arg(long, default_value_t = 6)]
        iterations: usize,
        /// Run full KiCad DRC on every layout attempt (slow; default is a single
        /// final-gate DRC).
        #[arg(long)]
        drc_every_iter: bool,
        /// Brand logo SVG to render on the back silk (bottom-centre).
        #[arg(long)]
        logo: Option<PathBuf>,
    },
    /// Generate a step-by-step visual assembly guide (HTML) from a circuit.
    Guide {
        /// Path to the circuit definition (e.g. a SKiDL script).
        circuit: PathBuf,
        /// Write the guide here (default: out/<name>/<name>-guide.html).
        #[arg(long)]
        out: Option<PathBuf>,
        /// Eurorack panel spec (TOML): build the vertical panel-anchored board.
        #[arg(long)]
        panel: Option<PathBuf>,
        /// Assembly kit type: auto (default; detects from pad types) | tht | smd |
        /// mixed. THT-first framing + copy â most DIY kits are through-hole.
        #[arg(long, default_value = "auto")]
        kit: String,
        /// Layout cost-function mode: analog | digital | mixed.
        ///
        /// Must match what `lob fab` is given, or the guide documents a different
        /// board from the one manufactured (`legion-of-bom-p6m`). Before this
        /// existed, `guide` had no way to be told and always laid out `analog`.
        #[arg(long, default_value = LAYOUT_MODE)]
        mode: String,
    },
    /// Import a board from another EDA tool.
    Import {
        #[command(subcommand)]
        action: ImportCmd,
    },
    /// Set up (or tidy) a circuits repo: write the .gitignore for lob's
    /// generated outputs, and report any generated files that are tracked.
    ///
    /// Idempotent â safe to re-run after upgrading lob to pick up new patterns.
    Init {
        /// Report what would change without writing anything.
        #[arg(long)]
        dry_run: bool,
    },
    /// Panel design: generate DXF, track orders.
    Panel {
        #[command(subcommand)]
        action: PanelCmd,
    },
    /// Concept -> spec: ask every typed decision for a design brief and write
    /// a spec -- raw text plus a machine-readable JSON, no schematic
    /// (legion-of-bom-utn). Needs OODA_API_KEY (and optionally OODA_BASE_URL
    /// for a local dev endpoint) -- see .env.example. Follow with
    /// `lob schematic` to render the circuit from the written spec.
    Spec {
        /// Circuit family from the curated library: "fuzz-pedal" or
        /// "stm32-codec".
        family: String,
        /// Free-text design brief, carried as decision context (not parsed for
        /// control flow -- the decisions, not the brief, choose the circuit).
        #[arg(long)]
        brief: String,
        /// Base output path (no extension): writes "<out>.json" (machine-
        /// readable, input to `lob schematic`) and "<out>.txt" (human-readable).
        #[arg(long)]
        out: PathBuf,
        /// Also write the full decision trace (JSON: key/type/chosen/confidence)
        /// here, for eval scoring (e.g. PCBBench).
        #[arg(long)]
        trace: Option<PathBuf>,
    },
    /// Concept -> spec, DAG variant: assemble a fuzz-pedal circuit as a
    /// chain of gain-stage nodes via sequential typed decisions ("add
    /// another stage, or stop?") instead of picking from one fixed
    /// two-stage template -- "rail -> node -> node -> ... -> output".
    /// Supply voltage and enclosure size are constraints on the request
    /// (specified, not decided); chain length, per-stage voicing, current
    /// budget, and tone-stack presence are real decisions. Needs
    /// OODA_API_KEY, same as `lob spec`.
    SpecChain {
        /// Free-text design brief, carried as decision context.
        #[arg(long)]
        brief: String,
        /// Supply rail voltage -- a constraint, not a decision (9.0 for a
        /// standard battery/adapter pedal, 18.0 for a two-battery/boosted one).
        #[arg(long, default_value_t = 9.0)]
        vcc: f64,
        /// Enclosure size class -- a constraint, not a decision: 1590b | 1590bb | 125b.
        #[arg(long, default_value = "1590b")]
        enclosure: String,
        /// Base output path (no extension): writes "<out>.json" and "<out>.txt".
        #[arg(long)]
        out: PathBuf,
        /// Also write the full decision trace (JSON) here.
        #[arg(long)]
        trace: Option<PathBuf>,
    },
    /// Spec -> design: render a SKiDL schematic from a spec file written by
    /// `lob spec`. A pure function of the spec -- no decision calls, no
    /// network -- so the schematic traces back to exactly what System One
    /// decided, replayably.
    Schematic {
        /// Spec JSON path (from `lob spec ... --out <base>`, i.e. "<base>.json").
        spec: PathBuf,
        /// Write the rendered SKiDL circuit here.
        #[arg(long)]
        out: PathBuf,
        /// Also write a Guitar Pedal panel TOML sized to the spec's enclosure
        /// class, with the Fuzz/Volume pots anchored to the circuit's RV1/RV2
        /// refdes -- a pure function of the spec, same as the schematic
        /// itself, so `lob board --panel <this file>` has real cutouts to
        /// check the circuit against without a further design decision.
        #[arg(long)]
        panel: Option<PathBuf>,
    },
}
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
fn main() -> ExitCode {
    // Load API keys before anything reads the environment.
    load_credentials();
    let cli = Cli::parse();
    init_tracing(cli.verbose);

    let result = match cli.command {
        Command::Run { circuit } => run(circuit),
        Command::Circuits => circuits_cmd(),
        Command::Build { circuit } => build_cmd(circuit),
        Command::Status => status_cmd(),
        Command::Serve { bind } => serve_cmd(bind),
        Command::Doctor => doctor::run(),
        Command::Init { dry_run } => init_cmd(dry_run),
        Command::Parts { action } => parts_cmd(action),
        Command::Bom {
            circuit,
            price,
            out,
            visual,
            smd,
        } => bom_cmd(circuit, price, out, visual, smd),
        Command::Board {
            circuit,
            out,
            panel,
            mode,
            iterations,
            logo,
            model: model_glb,
        } => board_cmd(circuit, out, panel, mode, iterations, logo, model_glb),
        Command::Diagram { circuit, svg, pdf } => diagram_cmd(circuit, svg, pdf),
        Command::ScopeProbe {
            circuit,
            input_net_hint,
            freq_hz,
            min_amplitude,
            max_amplitude,
            steps,
            out,
        } => scope_probe_cmd(
            circuit,
            input_net_hint,
            freq_hz,
            min_amplitude,
            max_amplitude,
            steps,
            out,
        ),
        Command::Drc { board } => drc_cmd(board),
        Command::Fab {
            circuit,
            out,
            panel,
            mode,
            iterations,
            drc_every_iter,
            logo,
        } => fab_cmd(circuit, out, panel, mode, iterations, drc_every_iter, logo),
        Command::Guide {
            circuit,
            out,
            panel,
            kit,
            mode,
        } => guide_cmd(circuit, out, panel, kit, mode),
        Command::Import { action } => import_cmd(action),
        Command::Panel { action } => panel_cmd(action),
        Command::Spec {
            family,
            brief,
            out,
            trace,
        } => spec_cmd(family, brief, out, trace),
        Command::SpecChain {
            brief,
            vcc,
            enclosure,
            out,
            trace,
        } => spec_chain_cmd(brief, vcc, enclosure, out, trace),
        Command::Schematic { spec, out, panel } => schematic_cmd(spec, out, panel),
    };

    match result {
        Ok(()) => ExitCode::SUCCESS,
        Err(err) => {
            // Print the full error chain, then fail with a non-zero code so the
            // pipeline is scriptable / CI-friendly.
            eprintln!("error: {err:#}");
            ExitCode::FAILURE
        }
    }
}

/// Run the pipeline against a circuit and report per-stage pass/fail.
///
/// Stages: SKiDL run â parse â simulate (ngspice AC) â verify (textbook cutoff).
/// Validate (ERC as structured findings) and BOM are the remaining Phase 0 tasks
/// and slot into the same report. Exits non-zero if any stage fails.
fn run(circuit: PathBuf) -> Result<()> {
    let circuit = circuit
        .canonicalize()
        .with_context(|| format!("circuit not found: {}", circuit.display()))?;

    let stem = circuit
        .file_stem()
        .and_then(|s| s.to_str())
        .unwrap_or("circuit");
    let work_dir = PathBuf::from("out").join(stem);

    tracing::info!(circuit = %circuit.display(), "lob run");
    println!("lob run: {}\n", circuit.display());

    let mut report = PipelineReport::new();

    // Stage: SKiDL â run the script, capture the netlist + ERC report.
    let runner = SkidlRunner::discover(&work_dir);
    let skidl_run = runner
        .run(&circuit)
        .with_context(|| "SKiDL stage failed (try `lob doctor`)")?;
    report.push(StageOutcome::passed("skidl").with(Finding::info(format!(
        "netlist: {}",
        skidl_run.netlist_path.display()
    ))));

    // Stage: parse the netlist into the internal Circuit model.
    let model =
        parse_netlist_file(&skidl_run.netlist_path).with_context(|| "parse stage failed")?;
    report.push(StageOutcome::passed("parse").with(Finding::info(format!(
        "{} parts, {} nets",
        model.parts().len(),
        model.nets().len()
    ))));

    // Stage: validate â surface ERC results as structured findings.
    report.push(validate_erc(skidl_run.erc_report.as_deref()));

    // Stage: simulate â generate a SPICE deck and run an ngspice AC sweep. Infer
    // the I/O and supply nets from the circuit (SIG_IN/SIG_OUT, +12V/-12V) rather
    // than assuming IN/OUT/Â±15 V (tus.9).
    //
    // Not every circuit has an audio-style signal path to sweep â a Pierce
    // oscillator's resonator network (crate::oscillator) has no IN/OUT at
    // all, only OSC_IN/OSC_OUT net labels with no consuming circuit. That's
    // not a broken circuit, it's a genuinely different shape (verified
    // analytically, not by SPICE â see that module's docs), and used to
    // hard-fail the *entire* pipeline here the same way a missing footprint
    // used to hard-fail the entire board (see the `not_placed` fix) â fixed
    // the same way: skip what doesn't apply, don't refuse what does.
    let sim_config = SimConfig::infer(&model);
    let net_names: std::collections::HashSet<&str> =
        model.nets().iter().map(|n| n.name.as_str()).collect();
    let has_io = net_names.contains(sim_config.input_net.as_str())
        && net_names.contains(sim_config.output_net.as_str());
    // Input and output joined only through parts the circuit declares out of
    // simulation (an ADC, a processor, a DAC) is a converter board, not an
    // analog signal path: there is no passband gain to measure.
    let converter_only = has_io
        .then(|| {
            legion_of_bom_core::spice::analog_path(
                &model,
                &sim_config.input_net,
                &sim_config.output_net,
            )
            .err()
            .filter(|via| !via.is_empty())
        })
        .flatten();
    let has_signal_path = has_io && converter_only.is_none();

    let ac_result = if has_signal_path {
        let ac = simulate_ac(&model, &sim_config, &work_dir)
            .with_context(|| "simulate stage failed (try `lob doctor`)")?;
        report.push(StageOutcome::passed("simulate").with(Finding::info(format!(
            "AC sweep: {} points, passband {:.2} dB",
            ac.points.len(),
            ac.passband_gain_db().unwrap_or(0.0)
        ))));

        // Stage: transient â a step response, which shows time-domain behaviour (a
        // slew limiter's peak slew rate) that an AC sweep can't (tus.10). Soft: a
        // circuit whose step response won't converge is surfaced, not fatal.
        match simulate_tran(&model, &sim_config, &TranAnalysis::default(), &work_dir) {
            Ok(t) => {
                let slew = t.max_slew_v_per_s().map_or_else(
                    || "n/a".to_string(),
                    |s| format!("{:.0} V/s ({:.2} V/ms)", s, s / 1e3),
                );
                report.push(
                    StageOutcome::passed("transient")
                        .with(Finding::info(format!("step response: peak slew {slew}"))),
                );
            }
            Err(e) => report.push(
                StageOutcome::passed("transient")
                    .with(Finding::warning(format!("step response did not run: {e}"))),
            ),
        }

        // Stage: crosstalk â a multi-channel circuit has a question a single-channel
        // one does not: do the channels stay independent? Drive channel 1 with a step
        // sequence, hold every other channel's input at 0, and probe both outputs
        // (tus.13 / 9wh). Self-selecting: skipped entirely on a single-channel board.
        if let Some(outcome) = crosstalk_stage(&model, &sim_config, &work_dir) {
            report.push(outcome);
        }
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

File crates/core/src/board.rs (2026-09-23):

//! Board generation — netlist → `.kicad_pcb`, directly as S-expression. DESIGN.md
//! 6.6 (revised: direct-gen, headless — the KiCad IPC API can't create boards).
//!
//! Architecture (forward-looking to the layout epic): board *emission* is
//! decoupled from *placement* via the [`Placer`] trait — the seam the iterative
//! layout loop (6.5), PanelSpec-anchored connectors (6.1/6.9), and the manual
//! escape hatch (6.8) all plug into. [`GridPlacer`] is the naive default; the
//! loop replaces it. Routing is a second seam — the [`Router`] trait (see the
//! [`route`](crate::route) module) — so tracks, the ground pour (6.2), and the
//! board outline are all appended to the same assembly by the generator.
//!
//! Output is deterministic (UUIDs derived from content) so each layout attempt is
//! a clean git diff, per 6.5.

use std::collections::{HashMap, HashSet, VecDeque};
use std::path::{Path, PathBuf};

use sha2::{Digest, Sha256};

use crate::logo::Logo;
use crate::model::Side;
use crate::route::{
    track_sexpr, via_sexpr, PadLayer, PadPoint, PathfinderRouter, RouteNet, RouteOptions,
    RouteOutput, Router, Track, Via,
};
use crate::sexpr::Sexpr;
use crate::source::CircuitSource;

/// Errors from board generation.
#[derive(Debug, thiserror::Error)]
pub enum BoardError {
    #[error("part {refdes} has no footprint assigned (needed to place it on a board)")]
    NoFootprint { refdes: String },
    #[error("footprint '{lib_part}' not found at {path}")]
    FootprintNotFound { lib_part: String, path: String },
    #[error("footprint parse error ({lib_part}): {msg}")]
    FootprintParse { lib_part: String, msg: String },
    #[error("i/o error: {0}")]
    Io(#[from] std::io::Error),
    #[error("{0}")]
    Other(String),
}

/// A placed footprint position: millimetres, degrees, and which copper side.
#[derive(Debug, Clone, Copy, PartialEq)]
pub struct Placement {
    pub x_mm: f64,
    pub y_mm: f64,
    pub rotation_deg: f64,
    pub back: bool,
}

/// What the placer needs to know about a part beyond the netlist: its footprint
/// keep-out size (mm), where that keep-out sits relative to the footprint origin,
/// and which side it mounts on.
#[derive(Debug, Clone)]
pub struct PartFacts {
    /// Keep-out size `(width, height)` — the courtyard (or pad box + margin).
    pub extent: (f64, f64),
    /// Physical **body** span `(width, height)` — the courtyard alone (or raw pad
    /// box), *without* the clearance margins and pin/lug inflation baked into
    /// `extent`. Those margins can distort a part's aspect (an Alpha pot's solder
    /// lugs stretch its keep-out taller than wide even though its body is
    /// landscape), so orientation decisions read this, not `extent`.
    pub body_extent: (f64, f64),
    /// Keep-out centre offset from the footprint origin. Not every footprint is
    /// centred on its origin — a DIP places the origin at pin 1, so its courtyard
    /// sits ~half the body away. Placers must offset the keep-out by this or a
    /// tightly-packed board trips `courtyards_overlap` even though the *origins*
    /// look clear. Defaults to `(0, 0)` (centred).
    pub origin_offset: (f64, f64),
    pub side: Side,
    /// Component height (mm). A part shorter than a sub-board's standoff may sit in
    /// the gap under its body (DESIGN 6.7).
    pub height_mm: f64,
    /// `Some(standoff)` if this part is itself a stacked sub-board.
    pub standoff_mm: Option<f64>,
    /// Through-hole pad keep-outs (mm rects, relative to the footprint origin,
    /// already clearance-expanded). Pins occupy *both* copper layers, so these are
    /// hard keep-outs every body avoids regardless of side — while the part's body
    /// itself is only on its own side.
    pub tht_pads: Vec<Rect>,
    /// Each pad's centre in footprint-local mm, by pad number.
    ///
    /// Decoupling is the reason this exists. "Put the bypass cap near the IC" is
    /// the wrong instruction — the loop that matters runs from the cap to the
    /// chip's *power pin*, and on a 16-pin package that pin is at the end, not
    /// the middle. Measuring part centres let a cap pass the rule at 8.7mm while
    /// sitting 10mm from the pin it was supposed to bypass, or on the far side of
    /// the chip entirely.
    pub pin_offsets: HashMap<String, (f64, f64)>,
}
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

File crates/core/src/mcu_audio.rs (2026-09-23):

//! `stm32-codec` — a small STM32H7 audio board: the first curated family that
//! is a digital board rather than an audio-band analog circuit (legion-of-bom-y17.8).
//!
//! One decision is made from the brief — which of three codec options to fit —
//! and everything else is either derived or cited:
//!
//! * **Pins** are connected by the names the official KiCad symbols give them
//!   (`u1.n["VDD"]`), never by numbers typed here, and every name — plus every
//!   pin-mux alternate a role relies on (`PE5` as `SAI1_SCK_A`) — is checked
//!   against the symbol file by [`check_symbols`]. KiCad's STM32 symbols are
//!   generated from ST's own pin data, so that is the cited source for the mux.
//! * **Values** — every capacitor, resistor and strap — carry an [`Evidence`]:
//!   a verbatim quote from a pinned datasheet page that [`crate::datasheet::verify`]
//!   checks mechanically, or a reading (a figure with no text layer, or a fact
//!   the pinned sources do not state) that counts only once a person confirms it
//!   ([`unconfirmed_facts`]).
//! * **Counts** are derived: the H7 gets one 100 nF per VDD pin because its
//!   datasheet says "N x 100 nF, N = number of VDD pins", and N is read from the
//!   symbol, not written here.
//!
//! TI's PCM5102A datasheet sets µ in a symbol font that `pdftotext` renders as a
//! plain "m": the quote "0.1mF 10mF" on its p.26 is 0.1 µF and 10 µF. The quote
//! is kept verbatim (that is what makes it checkable); the reading is in `what`.

use std::collections::BTreeMap;
use std::path::Path;

use ooda::{Client, Question, Request, Trace};
use serde::{Deserialize, Serialize};

use crate::datasheet::{Citation, Datasheet, Evidence};
use crate::oscillator::{fmt_pf, load_cap_pf, round_e12_pf, CrystalOption, CRYSTAL_CATALOG};
use crate::spec::{expect_choice, SpecError};
use crate::stage::StageError;
use crate::symbols;

// ---- pinned sources ---------------------------------------------------------
//
// Every datasheet is the distributor's (LCSC's) copy, pinned by hash.

pub static STM32H743_DS: Datasheet = Datasheet {
    part: "STM32H743VIT6",
    url: "https://datasheet.lcsc.com/datasheet/pdf/880ee2974c46763ce43da1468b8b0b74.pdf",
    sha256: "9c74d2015445f7c3c2c9076fc13a2665c8f6fecec7898d128dac836d6d39314b",
};
pub static PCM5102A_DS: Datasheet = Datasheet {
    part: "PCM5102APWR",
    url: "https://datasheet.lcsc.com/datasheet/pdf/427cb50cd71d4fa092a8afe7bc909457.pdf",
    sha256: "82970ecf973a6c13a4c729c43889501d4b5b4258614a9941a5660d3c355b3c3b",
};
pub static PCM1808_DS: Datasheet = Datasheet {
    part: "PCM1808PWR",
    url: "https://datasheet.lcsc.com/datasheet/pdf/123fc00b1e2e42d784540e014c38fb88.pdf",
    sha256: "a36e2bcd3b168e3efe4c3fc8dd3d0799e2f9fc84f99aca1fd24b82a9d2cf13db",
};
pub static WM8731_DS: Datasheet = Datasheet {
    part: "WM8731SEDS",
    url: "https://datasheet.lcsc.com/datasheet/pdf/d8923c62c1264cd78eaae0b5889c3563.pdf",
    sha256: "2862107246dc672cad4358a32c0b8b8e24954ba3eefad568971c44419f7ad8fa",
};
pub static ES8388_DS: Datasheet = Datasheet {
    part: "ES8388",
    url: "https://datasheet.lcsc.com/datasheet/pdf/b5b69a0d4875954a40e8f8a3f42483af.pdf",
    sha256: "db9300f79df430d022b754b29eb1b6b17ca08e3b91d3ba833606dadc65898258",
};
pub static AMS1117_DS: Datasheet = Datasheet {
    part: "AMS1117-3.3",
    url: "https://datasheet.lcsc.com/datasheet/pdf/e6935943fc6b1bbf350a1a0f3e90dc4a.pdf",
    sha256: "189a2651878a87d590b768eaa9b44217a3fdf460352ce6ecaff127221282a3f0",
};

const fn quote(source: &'static Datasheet, page: usize, quote: &'static str) -> Evidence {
    Evidence::Quote(Citation {
        source,
        page,
        quote,
    })
}

const fn figure(source: &'static Datasheet, page: usize, what: &'static str) -> Evidence {
    Evidence::Reading {
        source: Some(source),
        page,
        what,
        confirmed_by: None,
    }
}

const fn unsourced(what: &'static str) -> Evidence {
    Evidence::Reading {
        source: None,
        page: 0,
        what,
        confirmed_by: None,
    }
}

// ---- the decision -------------------------------------------------------------

/// Which codec the board carries — the one decision the brief makes.
#[derive(Debug, Clone, Copy, PartialEq, Eq, Serialize, Deserialize)]
#[serde(rename_all = "kebab-case")]
pub enum Codec {
    /// PCM5102A DAC + PCM1808 ADC: no control bus, pin-strapped, needs 5 V
    /// for the ADC's analog side.
    Pcm5102aPcm1808,
    /// WM8731: one I2C-configured codec with line and mic inputs.
    Wm8731,
    /// ES8388: one I2C-configured codec, low power, headphone-capable.
    Es8388,
}

impl Codec {
    pub const ALL: [Codec; 3] = [Codec::Pcm5102aPcm1808, Codec::Wm8731, Codec::Es8388];

    pub fn key(self) -> &'static str {
        match self {
            Codec::Pcm5102aPcm1808 => "pcm5102a-pcm1808",
            Codec::Wm8731 => "wm8731",
            Codec::Es8388 => "es8388",
        }
    }

    /// What a decider is told about the option — capabilities, not a verdict.
    fn describe(self) -> &'static str {
        match self {
            Codec::Pcm5102aPcm1808 => {
                "separate DAC + ADC chips, configured by pins only (no I2C), \
                 line level in and out, needs a 5 V rail"
            }
            Codec::Wm8731 => {
                "single codec configured over I2C, line inputs plus a microphone \
                 input, headphone driver, 3.3 V only"
            }
            Codec::Es8388 => {
                "single low-power codec configured over I2C, two stereo inputs, \
                 two stereo outputs including headphone, 3.3 V only"
            }
        }
    }
}
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

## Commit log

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2026-07-22 Scaffold Rust workspace + model roadmap in beads
    Convert the DESIGN.md §14 roadmap into a beads issue graph (one epic per
    phase, Phase 0 broken into the shortest end-to-end "working loop" path)
    and lay down the Rust foundation the pipeline plugs into.
    - Cargo workspace: legion-of-bom-core (lib) + lob (CLI).
    - core: DSL-agnostic Circuit model, the CircuitSource trait every stage
    reads through, composable Stage traits + PipelineReport/StageError.
    Boundary per DESIGN.md 2.3/3.3 so a future DSL/IR is one new impl.
    - lob CLI (clap): `run <circuit>` stub wiring in the Phase 0 stages,
    tracing-based logging, non-zero exit on failure.
    - Rust .gitignore (target/, out/), rustfmt.toml, documente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
    [main.rs, model.rs]
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2026-07-22 P0.1/P0.2: pin toolchain + `lob doctor` + RC low-pass demo circuit
    Tooling (P0.1):
    - core::tools — PATH+fallback tool discovery (ngspice, kicad-cli via macOS
    app bundle), version probing; unit-tested.
    - `lob doctor` — preflight reporting ngspice / kicad-cli / SKiDL / KiCad
    symbol libs with actionable hints; non-zero exit when a required tool is
    missing. Verified in both symbol-dir states.
    - requirements.txt pins skidl==2.2.3 (gitignored .venv); docs/TOOLING.md
    documents the verified toolchain and how lob locates each tool.
    Key finding: SKiDL 2.2.3 uses the kicad9 backend → needs KICAD9_SYMBOL_DIR.
    Circuit (P0.2):
    - examples/rc_lowpass.py — R1=1k, C1=159n → fc≈1.001kHz.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
    [main.rs]
2026-07-22 P0.3: SKiDL runner stage (script → netlist + ERC)
    - core::skidl::SkidlRunner shells out to the venv python, runs SKiDL in a
    scratch work dir (out/<name>/) so its *.erc/*.log/*_sklib.py artifacts stay
    out of the repo, and returns the netlist path + ERC report.
    - Careful path handling: the child runs with cwd=work_dir, so the interpreter
    and paths are absolutized — lexically (std::path::absolute), NOT canonicalize,
    to preserve the venv symlink (resolving it would run the base interpreter and
    lose skidl). Missing interpreter / non-zero exit → StageError, never panic.
    - core::skidl also centralizes python + symbol-dir discovery; doctor now reuses
    it (and correctly reports the m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
    [main.rs]
2026-07-22 P0.4: KiCad netlist parser → Circuit (first CircuitSource producer)
    - core::netlist: a self-contained S-expression reader (no new dependency)
    parses the KiCad netlist SKiDL emits into the internal Circuit model —
    parts (refdes/value/footprint/libsource) and nets (name + pins). Output is
    deterministically sorted (parts by refdes, nets by name, pins within a net)
    so downstream BOM/tests stay stable regardless of netlist ordering.
    - Wired as stage 2 of `lob run`: parses the netlist the SKiDL stage produced.
    `lob run examples/rc_lowpass.py` → "✓ parse 2 parts, 3 nets", exit 0.
    14 unit tests (incl. round-trip on an RC netlist fixture + parser edge cases);
    cargo check/test/buil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
    [main.rs]
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2026-07-22 P0.6/P0.7: ngspice AC simulation + textbook cutoff verification
    - core::units: SPICE/engineering value parser ("1k","159n",…) for analytic math.
    - core::spice: generate a SPICE deck from the Circuit (pin→net inversion,
    GND→node 0, R/C/L, a 1V AC source on IN + `.ac` sweep), run `ngspice -b`,
    parse the AC response. AcResult gives passband gain + an interpolated −3 dB
    cutoff (log-freq interpolation).
    - core::verify: assert the simulated −3 dB cutoff against 1/(2πRC) within a
    configurable tolerance; non-RC topologies are skipped, not failed.
    - lob run: PipelineReport-driven pipeline (skidl → parse → simulate → verify)
    with per-stage pass/fail report and non-zero exit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
    [main.rs]
2026-07-22 P0.5/P0.8/P0.9: validate + BOM stages complete the Phase 0 loop
    - core::validate: turn the SKiDL ERC report into structured findings; fail the
    stage only on ERC errors (warnings — e.g. the RC demo's open-port notices —
    pass).
    - core::bom: group parts by (value, footprint) into BOM lines with qty +
    refdes; CSV export, aligned terminal table, missing-footprint flagging.
    - lob run: full DESIGN-order pipeline — skidl → parse → validate → simulate →
    verify → bom — with a per-stage pass/fail report, a printed BOM, a written
    BOM CSV, and non-zero exit on any failure.
    `lob run examples/rc_lowpass.py`: all 6 stages ✓, pipeline passed, exit 0.
    30 core tests; cargo check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
    [main.rs]
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2026-07-22 P0.10: op-amp demo via component-carried SPICE models (no per-device branches)
    Addresses the feedback that hardcoding an op-amp's SPICE model in the generator
    is an anti-pattern: a component's model must travel WITH the component.
    - core::sexpr: promoted the S-expr reader out of netlist.rs into a shared module.
    - core::symbols: resolve a part's SPICE model FROM the component — reads the
    KiCad symbol's Sim.Device/Sim.Name/Sim.Library/Sim.Pins (which SKiDL's netlist
    path drops) plus the .sp subckt terminal order. This is the seam the Dolt
    parts library plugs into later.
    - core::spice: SpiceModel::Subckt; generate_ac_deck is now model-driven —
    instantiates subckt models (X-line + .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
    [main.rs, model.rs]
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2026-07-22 okm.7: resolve circuit parts by MPN against the parts library
    The bridge circuits cross to reach verified part data — unblocks BOM pricing
    and the verification gate.
    - model::Part gains `mpn: Option<String>` (+ with_mpn builder); the netlist
    parser extracts an `MPN` custom field (case-insensitive) from each component.
    - parts::PartsLibrary::resolve_circuit → PartResolution { refdes, mpn, record,
    status } with ResolutionStatus (NoMpn | Unknown | Unverified | Verified).
    - `lob parts resolve <circuit>` runs SKiDL → parse → resolve and prints per-part
    status + a verified count.
    Verified end-to-end: a SKiDL circuit setting `MPN=LM13700` resolves against the
    fetched LM13700 record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
    [main.rs, model.rs]
2026-07-22 zya.1/2/3: Mouser-priced BOM (live pricing + priced CSV)
    The layout-independent priced BOM the project most wanted.
    - core::mouser: thin ureq client for Mouser's Search API — search_mpn(mpn)
    returns PartPrice (matched MPN, stock, quantity price breaks); unit_price_at
    picks the applicable break. Parses "$1.48"-style prices; from_env reads
    MOUSER_API_KEY. Response parsing unit-tested against a fixture (no network).
    - core::bom: BomLine gains mpn + unit_price + ext_price; parts group by
    (mpn, value, footprint); Bom::total(); CSV + table now carry price columns.
    - CLI: `lob bom <circuit> [--price] [--out <csv>]`; .env auto-loaded (dotenvy)
    so keys are picked up without exporting.
    V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
    [main.rs]
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2026-07-22 okm.4: verification gate — block unverified parts
    The keystone enforcement of the parts library: PartResolution::blocks_verified_use
    (true for MPN-bearing parts that are Unknown or Unverified) and
    `lob parts gate <circuit>`, which resolves a circuit and exits non-zero if any
    part isn't human-verified. This is the check layout / real BOM ordering enforce —
    the structural block against unverified part data (the LM13700-from-memory fix).
    Verified: gate FAILS (exit 1) on an unverified part, PASSES once verified.
    [main.rs]
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2026-07-22 j54.5: board generation — netlist → .kicad_pcb (direct S-expr, headless)
    The biggest missing pipeline stage, ported from the validated prototype.
    - core::sexpr: rewritten as a reader AND writer — Sym/Str variants keep symbols
    bare and strings quoted so files round-trip; adds a serializer + builders.
    (netlist/symbols unaffected — all access is behind the accessors.)
    - core::board: generate_board(circuit, options) → a valid .kicad_pcb. Loads
    footprint .kicad_mod files, places + net-wires them, assembles the board
    (2-layer stack + net table + footprints). Deterministic UUIDs (sha2 of
    content) → clean git diffs per DESIGN 6.5.
    - Forward-looking architecture: emission is de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
    [board.rs, main.rs]
2026-07-22 j54.2: board outline + 2-layer ground pour (DESIGN 6.2)
    The generated board is now manufacturable and analog-correct:
    - Board outline: an Edge.Cuts rectangle (bounding box of placed parts + margin).
    This alone took DRC from 1 violation → 0 (the courtyard issue was the missing
    outline). Real panel-driven outlines arrive with PanelSpec (j54.10).
    - Bottom-layer ground pour: a B.Cu zone flooded to GND (DESIGN 6.2's default
    convention — replaces manual star-ground). Emitted via the seam left in
    generate_board; kicad-cli fills it on export with `--check-zones` (B.Cu gerber
    459 → 965 bytes, i.e. the pour plots).
    - BoardOptions gains `ground_net` (default "GND") + `outline_margin_mm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
    [board.rs, main.rs]
2026-07-22 Add two-layer obstacle-aware routing (Layout 6.5a, j54.12)
    Route placed nets into copper via a new Router seam (analogous to Placer).
    GridRouter is a 2-layer maze router: rasterise the board, mark other nets'
    pads + committed copper as obstacles (inflated by clearance), and Dijkstra a
    least-cost path per connection, dropping a via to the back copper to cross.
    MstRouter stays as a naive straight-line baseline / test double.
    generate_board now emits (segment …)/(via …) alongside footprints + pour, and
    generate_board_report surfaces any unrouted connections instead of shipping a
    silently incomplete board. Trace/via/clearance defaults follow real Eurorack
    practice (0.25mm traces, 0.8/0.4mm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
    [board.rs, main.rs]
2026-07-23 Real op-amp: model travels with the part; kill device-sniffing (okm.12)
    The op-amp demo used the ideal Simulation_SPICE:OPAMP (no footprint), so it
    couldn't be laid out, routed, or ordered. Make U1 a real TL072 (SOIC-8, MPN
    TL072CDR) that flows through the WHOLE pipeline.
    Mechanism — the SPICE model travels WITH the part, not as a per-device branch:
    - Part gains a `sim: Option<SimModel>` (Sim.Device/Name/Library/Pins).
    - netlist parses those fields (SKiDL passes manually-set fields through).
    - the symbols resolver prefers the part-carried model, falling back to the
    shipped symbol for KiCad's ideal parts. TL072 is modelled with the built-in
    op-amp subckt mapped onto its real, symbol-ve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
    [board.rs, model.rs]
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2026-07-23 Double-sided boards: side-aware placement + back-flip emission (j54.16)
    Parts now resolve to a board side and emit correctly on it:
    - resolve_side: through-hole parts (any *.Cu pad) -> back, SMD -> front (DESIGN
    6.1); threaded through the Placer via a new PartFacts {extent, side}.
    - transform_footprint flips a back part properly: swap every child F./B. layer,
    mirror local X, and mirror back-layer text ((justify mirror)); place_point
    mirrors pad X to match so routing lands on the real pads.
    - board outline is now the real placed-pad bounding box (a big part's pads no
    longer spill past the edge).
    Also fixes a latent router bug the THT part exposed: vias got only trace-sized
    clearance.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
    [board.rs]
2026-07-23 feat(panel): PanelSpec trait + Eurorack impl + DXF export + order tracking
    Implements DESIGN.md §6.9 (PanelSpec trait) and §7.1/7.5 (DXF + order tracking).
    PanelSpec trait
    - Format-agnostic seam: width_mm, height_mm, thickness_mm, mounting_holes, cutouts
    - No Eurorack concepts (HP/U) leak into the trait; all dimensions in mm
    - Only Eurorack implemented; pedal/rack/500-series deliberately unimplemented
    EurorackPanel
    - Builder API: new(hp), with_thickness, with_cutout, with_cutout_rotated
    - Auto-generates mounting holes per Doepfer standard (2 holes < 8 HP, 4 holes ≥ 8 HP)
    - Standard footprint library: Thonkiconn, Alpha9mm, LED_3mm/5mm, toggle, M3
    DXF export
    - Minimal ASCII DXF writer (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
    [main.rs]
2026-07-23 Double-sided: declared per-part side, not inferred (fix j54.16)
    Side is a per-board/per-part design choice, not a function of SMD-vs-through-hole
    (Mutable boards mix both yet mount everything on one side; Super Synthesis is
    double-sided with the SMD/signal bulk on the ground-poured back and the panel
    interface on the front — confirmed from their pick-and-place).
    So replace the wrong auto-split with an explicit declaration:
    - model: Side {Front,Back} + Part.side: Option<Side> + Side::parse; default front.
    - netlist parses a `Side` field (SKiDL passes it through) onto Part.side.
    - generate_board threads part.side to the placer; no inference from pad tech.
    The back-flip emission from the pr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
    [board.rs, model.rs]
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2026-07-23 DRC readback: the layout loop's check step (j54.11)
    core::drc runs KiCad's DRC headlessly (kicad-cli pcb drc --format json
    --refill-zones) and parses it into a structured DrcReport (violations,
    unconnected_items, schematic_parity) with severity helpers (errors/warnings/
    is_clean). This is the "check" step (DESIGN 6.5 step 3) the iterative layout
    loop (j54.6) repairs against.
    De-risk: the bead scoped kicad-ipc-rs, but that needs a *running* KiCad with the
    IPC plugin. kicad-cli gives the same DRC data headlessly — the same reason board
    generation is direct-gen, not IPC. Live-KiCad IPC stays an option for interactive
    editing, not the loop's automated check.
    CLI: `lob drc <board>` reports er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
    [main.rs]
2026-07-23 lob fab: DRC-gated JLCPCB manufacturing package (nxo.4)
    `lob fab <circuit>` produces the upload-ready package to order a board:
    - generate board -> DRC gate (run_drc, j54.11): refuse to package a board with
    errors; warnings pass.
    - Gerbers + drill (kicad-cli), auto-zipped into <name>-gerbers.zip (the PCB
    upload — files at the archive root, JLCPCB's expected form).
    - JLC CPL <name>-cpl.csv: Designator,Mid X,Mid Y,Layer,Rotation, reformatted
    from kicad-cli's position export (top/bottom -> Top/Bottom).
    - JLC BOM <name>-bom.csv: Comment,Designator,Footprint,LCSC Part #, from the
    grouped BomLines (MPN -> LCSC column).
    core::fab holds the reusable pieces (pure formatters unit-tested; ki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
    [main.rs]
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2026-07-23 guide: per-part footprint-aware polarity + silkscreen markers (mib.7)
    Polarity is now resolved per part, not blanket per kind: detect_polarity reads
    the footprint so an electrolytic/tantalum cap (CP_/Elec/Tantal) is flagged + while
    a ceramic C_ is not; diodes/LEDs -> cathode (K); ICs/transistors/connectors ->
    pin 1. The SVG draws a marker (K / + / 1) at the part's reference pad (pin-1
    position parsed from the board), so the builder aligns it to the board's
    silkscreen mark; the per-step caution appears only when the step actually has
    polarised parts.
    Adds examples/rectifier.py (diode + electrolytic cap + resistor) to exercise both
    polarity kinds — the guide marks D1's cathode and C1's + te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
    [guide.rs]
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2026-07-23 guide: embed real KiCad board raster in the PDF build guide
    The PDF guide now uses KiCad's real board plot as the per-step diagram
    (matching the HTML), replacing the schematic top-down. Each step's parts
    are drawn as outlined markers so the real copper/pads show through, with
    refdes + polarity/pin-1 dots at true board-mm coordinates. Verified across
    electrolytic +, IC pin-1, and diode-cathode markers.
    - fab: render_board_jpeg — export pdf (copper+silk+edge, F.Fab dropped) →
    QuickLook high-res raster → sips JPEG, with a direct-sips fallback; missing
    tools degrade to the schematic diagram rather than failing the guide.
    - pdf: Image/from_jpeg (SOF dims) + Page::draw_image (clip + cm)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
    [guide.rs, main.rs]
2026-07-23 board: guarantee visible silkscreen refdes (silkscreen v0, j54.14)
    Silk (reference designators, polarity marks, pin-1 indicators) already
    renders on F.SilkS/B.SilkS because transform_footprint places whole KiCad
    library footprints — each brings its own silk graphics, and back parts
    mirror to B.SilkS via flip_to_back. The one real gap was visibility: some
    library footprints ship the Reference property hidden, which would hide the
    refdes a hand-assembler needs. transform_footprint now strips (hide yes) /
    bare hide on the Reference so the designator always renders on silk.
    Locks the behavior with two regression tests (front keeps silk + unhides
    refdes; back mirrors silk + refdes to B.SilkS).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
    [board.rs]
2026-07-23 drc: surface silkscreen collisions as a distinct category (j54.15)
    Silk-over-pad / silk-over-silk / silk-over-edge aren't electrical, so the
    copper DRC passes them silently — but they garble the refdes/polarity legend
    a hand-assembler reads from the build guide. The layout loop's check step
    now surfaces them explicitly:
    - DrcViolation::is_silkscreen_collision — classifies KiCad's silk keys
    (silk_overlap, silk_over_copper, silk_edge_clearance) by the "silk"
    substring, so a new variant is caught without a spelling update.
    - DrcReport::silkscreen_collisions / silkscreen_collision_count.
    - CLI `lob drc` reports "(N silkscreen)" in the summary and lists each with
    its board location, in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
    [main.rs]
2026-07-23 guide: photorealistic unpopulated board renders with accurate overlays (dqk.1-3)
    Replace the flat 2D-plot guide diagram with a photorealistic UNPOPULATED
    board render — kicad-cli `pcb render --side top` (green soldermask, ENIG
    pads, white silk), 3D component models stripped so the builder sees the bare
    pads to populate. This is what the board looks like fresh from the fab.
    The render is orthographic and the board is centred, so board-mm map into
    the image analytically — scale = 0.70·min(W/w_mm, H/h_mm) about the image
    centre — with W/H read from the PNG header (no pixel decode). Validated:
    highlight boxes and polarity/pin-1 dots land dead-on the pads.
    - fab::render_board_png (strip_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
    [guide.rs, main.rs]
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2026-07-23 board: seed no-net pads as routing obstacles (fix DRC shorts, tus.5)
    The router only received pads belonging to routed nets, so pads carrying no
    net — unused IC pins, jack switch contacts, spare header pins — were invisible
    to it and traces routed straight through them. On the first real board (the
    Puget slew limiter) that was 24 DRC shorting_items errors.
    generate_board_report now collects no-net pads and passes each as its own
    single-pad RouteNet (net 0): GridRouter paints every net's pads (+clearance
    halo) as obstacles but only routes nets with >=2 pads, so these become
    route-around obstacles that are never themselves connected.
    Slew limiter DRC: 24 shorting errors -> 0 (remaining 1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
    [board.rs, guide.rs, main.rs]
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2026-07-23 board/route: two-sided ground + front-biased signals -> slew limiter DRC-clean (tus.8)
    Fuller routing (tus.6) carved the single B.Cu ground pour into an island, so
    C2's ground pad got thermal relief to isolated copper (starved_thermal). Two
    fixes, together making the ground plane whole:
    - board: pour ground on BOTH copper layers (the many through-hole GND pads
    bridge them) with island_removal on — a two-sided ground is also quieter for
    an analog signal path (DESIGN 6.2).
    - route: a small per-step surcharge for the back layer (RouteOptions
    .back_penalty_mm, default 0.1mm) biases signals onto the front so the back
    stays a mostly-intact ground plane. It's tuned under one via's cost,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
    [board.rs]
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2026-07-23 board: vertical Eurorack format with panel-anchored placement (j54.20)
    The main board came out as a wide landscape strip (178x52mm, ~35HP) because
    GridPlacer rows parts out and the outline is their bbox — nothing Eurorack.
    Adds panel-anchored vertical placement:
    - EurorackPlacer: panel-facing parts (jacks, pots) are anchored at their panel
    cutout positions (Y flipped from the panel's bottom-up frame to KiCad
    top-down) so the board mates the panel PCB; the rest are spread down the tall
    board by first-fit collision placement (evenly distributed rows, each taking
    the nearest courtyard-clear spot).
    - Panel cutouts gain an optional `refdes` (Cutout/CutoutFile) linking them to
    board p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
    [board.rs, main.rs]
2026-07-23 cli: wire --panel into `lob fab` and `lob guide`
    Both now accept `--panel <spec.toml>` and build the vertical panel-anchored
    board (via the shared board_options_with_panel helper) instead of the default
    bounding-box strip — so the DRC-gated manufacturing package and the build guide
    use the real Eurorack board, matching the panel PCB.
    Verified: `lob fab slew_limiter.py --panel …` produces a DRC-clean (0 errors)
    vertical 3U board (40.6×128.5mm) with gerbers + CPL (11) + BOM (9).
    Gates: 112 tests pass, fmt clean, clippy -D warnings clean.
    Claude-Session: https://claude.ai/code/session_01APSD9MyK5tBPQLXHDoTZzq
    [main.rs]
2026-07-23 board/panel: centre the Eurorack board + panel on the KiCad sheet
    The panel-anchored board and the panel PCB were emitted at (0,0), so they sat
    jammed in the corner of KiCad's A4 sheet — cosmetic, but jarring to open and
    inconsistent with the default boards (which land near sheet centre). Both are
    now centred on the A4 landscape sheet: EurorackPlacer gains an origin_mm applied
    to every placement (with the outline offset to match), and panel_to_kicad_pcb
    offsets its geometry likewise.
    Board + panel now centre exactly on (148.5, 105). Manufacturing is unaffected:
    DRC still 0 errors, and CPL coords stay board-relative (aux_axis_origin moves
    with the board), so JLCPCB placement is unchanged.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
    [board.rs, main.rs]
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2026-07-24 router: keep copper an edge-clearance inset inside the board outline (j54.23)
    The GridRouter was never told where the board edge is: route_options.bounds
    stayed None, so it routed against the pad bounding box and freely laid tracks
    and vias onto Edge.Cuts. On a wide board there's slack so nothing hit the edge;
    on a tight (narrow-HP) board it produced copper_edge_clearance DRC errors.
    - RouteOptions.edge_clearance_mm (default 0.5, matching KiCad's copper_edge_
    clearance). When `bounds` is the board outline, route_pass insets the routable
    area by edge_clearance + the widest copper half (a via), so no track or via
    lands within the clearance of the edge. A net whose only path runs through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
    [board.rs]
2026-07-24 board: drop unfittable parts into an off-board lane, not onto the edge (j54.24)
    Both panel placers (SeededPlacer, EurorackPlacer) shared an overflow fallback of
    `(x0, y1 + 2.0, ...)` for a free part that fits nowhere. y1 is the usable-area
    top (height - margin), so y1 + 2 sits only ~1mm inside the bottom edge: the part
    straddled the outline and tripped copper_edge_clearance — a misleading clearance
    error for what is really "this part could not be placed."
    overflow_drop() now stacks such parts in an off-board lane a clear gap (2mm)
    *below* the bottom edge, so no copper lands within edge clearance. The genuine
    failure surfaces honestly downstream instead — the part's nets are left unroute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
    [board.rs]
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2026-07-24 board: GND stitching vias reconnect pour islands under dense THT grids (25z.2)
    The two-sided ground pour (DESIGN 6.2) relies on through-hole GND pads to bridge
    its F.Cu/B.Cu layers. Where a GND pad sits alone in a region a dense THT grid (a
    sub-board header) fenced off, its pour becomes an isolated island and KiCad flags
    starved_thermal (the daisy_demo board's only DRC error).
    ground_stitching_vias places a GND via just off each through-hole ground pad,
    tying the two pours together locally so the island reconnects to the intact pour
    on the other layer. Each via stays inside the board edge and clear of all
    other-net copper (pads, tracks, vias); a pad with no clear spot around it is
    skipped r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
    [board.rs]
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
